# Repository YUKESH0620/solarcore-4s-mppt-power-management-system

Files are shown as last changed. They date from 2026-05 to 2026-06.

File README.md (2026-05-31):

# Solar Energy Harvesting and Battery Management Platform (STM32)  
## SolarCore-4S MPPT Power Management System

## 1. Project Banner










---

## 2. Project Overview

SolarCore-4S MPPT Power Management System is an embedded power electronics platform focused on solar energy harvesting, battery charging, battery management, and protected multi-rail power distribution. The design integrates a dedicated embedded control node based on **STM32F103C8T6**, a **BQ76920** battery management subsystem for 4S LiFePO4 supervision, and supporting power-stage/control interfaces for charge-discharge path management.

The platform architecture is modular at schematic and PCB level, enabling clear partitioning of solar input conditioning, MPPT-oriented conversion stages, battery protection, sensing, and regulated output distribution. The hardware has been developed through a professional PCB workflow in **Altium Designer**, including completed schematic capture, 4-layer layout, and Draftsman documentation generation.  

This repository documents the hardware architecture and design workflow. Hardware manufacturing and validation are pending.

---

## 3. Key Features

| Feature | Description |
|---|---|
| MPPT Energy Harvesting | Solar input processing architecture prepared for MPPT-driven energy extraction workflow |
| STM32 Control | Central embedded supervision and control using STM32F103C8T6 |
| 4S LiFePO4 Monitoring | Multi-cell battery stack monitoring architecture for 4S LiFePO4 systems |
| BQ76920 Protection | Cell monitoring and protection support through BQ76920 BMS IC |
| Charge/Discharge Control | Dedicated charge and discharge path control stages in hardware |
| Protected Outputs | Output connectors include protection-focused design intent |
| Power Distribution | Multi-rail distribution strategy for downstream loads |
| USB-C Debug Interface | USB Type-C debug/programming interface via CP2102N USB-UART bridge |
| Battery Monitoring | Voltage/current observation paths for embedded diagnostics |
| 4 Layer PCB Design | Layered signal-power-ground architecture for improved layout control |
| Draftsman Documentation | Formal assembly and fabrication-oriented documentation generated |
| Manufacturing Package Generation | Manufacturing outputs prepared (Gerber, NC drill, BOM, and related files) |

---

## 4. System Architecture

```mermaid
flowchart LR
    SI[Solar Input] --> IP[Input Protection]
    IP --> MPPT[MPPT Buck Converter]
    MPPT --> BCN[Battery Charging Node]
    BCN --> CDP[Charge/Discharge Protection]
    CDP --> BP[4S LiFePO4 Battery Pack]

    BP --> BMS[BQ76920 BMS]
    BP --> PDS[Power Distribution System]

    PDS --> R12[12V Rail]
    PDS --> R5[5V Rail]
    PDS --> R33[3.3V Rail]
    PDS --> PO[Protected Outputs]

    STM[STM32F103C8T6] <--> BMS
    STM <--> CS[Current Sensing]
    STM <--> VS[Voltage Sensing]
    STM <--> USB[USB Debug]
```

---

## 5. Hardware Architecture Overview

The hardware is partitioned into functionally distinct yet electrically integrated subsystems:

- **Solar Input Subsystem**  
  Accepts photovoltaic input and routes energy through front-end protection and conditioning stages before converter entry.

- **MPPT Subsystem**  
  Implements the hardware path required for MPPT-controlled conversion and battery charging node regulation.

- **Current Sensing Subsystem**  
  Provides analog/current feedback paths for embedded measurement and control-loop observability.

- **Voltage Sensing Subsystem**  
  Enables monitored voltage points across input, battery, and distribution nodes for supervisory logic.

- **Battery Protection Subsystem**  
  Uses BQ76920-centric monitoring/protection architecture for a 4S LiFePO4 pack context.

- **Power Switching Subsystem**  
  Controls charge/discharge path gating and operating-state transitions through dedicated switching stages.

- **Power Distribution Subsystem**  
  Distributes stored energy into required system rails and protected load outputs.

- **Output Protection Subsystem**  
  Integrates protective output routing strategy for external interfaces and load-side safety.

- **USB Debug Subsystem**  
  CP2102N-based USB-UART communication interface for firmware debug/programming workflow.

- **Embedded Controller Subsystem**  
  STM32F103C8T6 supervises sensing, BMS communication, and control sequencing at system level.

---

## 6. Complete Schematic Documentation

### Sheet 1 – System Architecture



- **What it does:** Defines top-level electrical partitioning and subsystem interconnections.  
- **How it connects:** Serves as the integration map linking energy path, control path, sensing path, and interfaces.  
- **Important components:** System-level interconnect blocks, power path references, controller interaction boundaries.  
- **Why it exists:** Establishes traceable architecture before detailed per-sheet implementation.

### Sheet 2 – STM32 Controller and Monitoring System



- **What it does:** Implements the STM32F103C8T6 control core and measurement interface endpoints.  
- **How it connects:** Interfaces with sensing networks, BMS communication paths, and debug/programming ports.  
- **Important components:** STM32F103C8T6, analog acquisition interfaces, communication lines, support passives.  
- **Why it exists:** Centralizes supervisory control and monitoring signal acquisition.

### Sheet 3 – 4S LiFePO4 Battery Management System (BMS)



- **What it does:** Defines multi-cell monitoring and battery protection topology for 4S LiFePO4.  
- **How it connects:** Ties directly to the battery stack and exchanges status/control data with the controller domain.  
- **Important components:** BQ76920 and associated sensing/protection support network.  
- **Why it exists:** Provides battery safety monitoring architecture and protected battery operation framework.

### Sheet 4 – Charge and Discharge Protection Stage



- **What it does:** Implements controlled charge/discharge path switching and protection behavior.  
- **How it connects:** Sits between charging node, battery pack, and downstream distribution interfaces.  
- **Important components:** IR2104-based drive/control elements and switching-stage support circuitry.  
- **Why it exists:** Enables controlled energy flow while enforcing protection-focused operating transitions.

### Sheet 5 – Output Connectors and Protection



- **What it does:** Defines external output connectors and protection elements for load interfacing.  
- **How it connects:** Receives power from distribution rails and routes to protected output endpoints.  
- **Important components:** Output connectors, protection devices, interface conditioning components.  
- **Why it exists:** Standardizes safe external power access points.

### Sheet 6 – Power Distribution and Voltage Rails



- **What it does:** Implements rail generation/distribution strategy for system and external loads.  
- **How it connects:** Receives upstream battery-sourced power and feeds 12V, 5V, and 3.3V domains.  
- **Important components:** LM3478-related control/distribution stage and rail routing support circuitry.  
- **Why it exists:** Provides organized multi-rail power availability across platform domains.

### Sheet 7 – USB Type-C Debug and Programming Interface



- **What it does:** Provides USB Type-C based debug/programming communication access.  
- **How it connects:** Bridges USB interface to MCU UART/debug domain through CP2102N.  
- **Important components:** CP2102N, USB Type-C connector, protection/interface passives.  
- **Why it exists:** Supports embedded development workflow and diagnostics without dedicated external adapters.

---

## 7. PCB Design Overview

The PCB is implemented as a **4-layer stackup** in Altium Designer:

| Layer | Function |
|---|---|
| Layer 1 | Top Signal |
| Layer 2 | Ground Plane |
| Layer 3 | Power Plane |
| Layer 4 | Bottom Signal |

Design strategy emphasizes:

- **Power integrity:** Controlled distribution over dedicated power plane regions and short high-current paths.  
- **Ground return paths:** Continuous ground reference on Layer 2 to reduce loop area and improve return continuity.  
- **Noise control:** Functional zoning between switching power stages, analog sensing, and controller/debug sections.  
- **Power distribution:** Structured rail routing from battery/power stages to 12V, 5V, and 3.3V destinations.  
- **Thermal considerations:** Copper utilization and via-based heat spreading around power-dense regions.  
- **Placement methodology:** Source-to-load path minimization and subsystem clustering by function.

---

## 8. PCB Layout Strategy

- **Power stage placement:** Converter and switching stages positioned to minimize high-di/dt loop lengths.  
- **Controller placement:** STM32 and monitoring circuits placed in a lower-noise control region.  
- **BMS placement:** BQ76920 and cell monitoring network grouped for short, coherent battery sense routing.  
- **USB placement:** USB Type-C and CP2102N placed for clean interface routing and practical access.  
- **Connector placement:** Power/output connectors arranged for clear current flow and service accessibility.  
- **Routing methodology:** Hierarchical routing from high-power nets first, followed by control/analog interfaces.  
- **Grounding strategy:** Ground-plane continuity maintained with deliberate partition-aware return management.  
- **Thermal vias:** Used near thermally active components to improve heat transfer into internal copper.  
- **Power planes:** Layer 3 segmented/organized to support multiple voltage domains and controlled distribution.  
- **Manufacturability considerations:** Clearances, drill constraints, and assembly access considered during layout finalization.

---

## 9. PCB Images

## PCB Top View



Top-side view showing component distribution, power-stage zoning, and control-domain placement.

## PCB Bottom View



Bottom-side view highlighting complementary routing channels, plane interactions, and connector breakout strategy.

## PCB Perspective View



Perspective rendering for holistic visualization of mechanical placement balance and subsystem segregation.

---

## 10. Draftsman Documentation

## Assembly Drawing



Documents component references, placement orientation, and assembly guidance for board population workflow.

## Layer Documentation



Provides per-layer visual references and stack representation to support fabrication and design review.

## Manufacturing Documentation



Consolidates production-facing notes, callouts, and output package references for fabrication handoff.

---

## 11. Manufacturing Outputs

| Output | Status |
|---|---|
| Gerbers | Generated |
| NC Drill Files | Generated |
| Assembly Drawings | Generated |
| Fabrication Drawings | Generated |
| BOM | Generated |
| Pick and Place Data | Generated |
| PCB PDF | Generated |
| Schematic PDF | Generated |

---

## 12. Firmware Architecture

```mermaid
flowchart TD
    A[Startup] --> B[Hardware Initialization]
    B --> C[ADC Sampling]
    C --> D[Current Measurement]
    D --> E[Voltage Measurement]
    E --> F[BMS Monitoring]
    F --> G[MPPT Control Loop]
    G --> H[Power Management]
    H --> I[Fault Detection]
    I --> J[User Feedback]
    J --> C
```

---

## 13. Firmware Workflow

- **STM32 role:** Central execution node for supervisory logic and subsystem coordination.  
- **ADC acquisition:** Periodic analog sampling for operational observability.  
- **Current sensing:** Charge/discharge path current data is acquired for control and protection context.  
- **Voltage sensing:** Battery/system voltages are monitored for state supervision.  
- **BMS communication:** Controller interfaces with BMS telemetry/protection information paths.  
- **Battery monitoring:** Multi-parameter battery condition tracking supports safe workflow decisions.  
- **Fault management:** Fault checks gate protective responses and user-visible status handling.  
- **Future MPPT implementation:** Control algorithm refinement and hardware-coupled tuning are planned after bring-up.

---

## 14. Repository Structure

```text
SolarCore-4S MPPT Power Management System/
├── Docs/
├── Hardware/
├── PCB/
├── Schematics/
├── Draftsman/
├── Firmware/
├── Manufacturing/
├── Images/
└── BOM/
```

---

## 15. Design Highlights

| Area | Implementation |
|---|---|
| Controller | STM32F103C8T6 |
| Battery Management | BQ76920 |
| Gate Drive | IR2104 |
| Power Distribution Control | LM3478 |
| USB-UART Interface | CP2102N |
| PCB Technology | 4-Layer PCB |
| Distribution Topology | Multi-rail protected power distribution |
| Debug Interface | USB Type-C debug/programming path |

---

## 16. Future Development

The following activities are planned for subsequent project phases:

- PCB manufacturing and fabrication release execution  
- Hardware assembly and staged bring-up  
- Firmware development completion and integration  
- MPPT functional validation on manufactured hardware  
- Thermal characterization under defined operating scenarios  
- Efficiency measurements across representative load/input conditions  
- System-level optimization based on bring-up and validation results

---

## 17. Project Status

- [x] System Architecture
- [x] Schematic Design
- [x] PCB Layout
- [x] Draftsman Documentation
- [x] Manufacturing Files
- [ ] PCB Fabrication
- [ ] Assembly
- [ ] Firmware Development
- [ ] Hardware Bring-Up
- [ ] Validation Testing

> Current status: Hardware design artifacts are complete; manufacturing and hardware validation are pending.

---

## 18. License

This project is licensed under the **Creative Commons Attribution-NonCommercial-NoDerivatives 4.0 International License (CC BY-NC-ND 4.0)**.

### You are permitted to:

- View and study the project
- Use the project for educational purposes
- Share links to this repository
- Reference the work with proper attribution

### You may NOT:

- Use any part of this project for commercial purposes
- Modify and redistribute the design files
- Reproduce the PCB, schematic, firmware, or documentation for commercial products
- Publish derivative works based on this project without explicit permission

All design files, schematics, PCB layouts, firmware, documentation, images, and manufacturing outputs remain the intellectual property of the author unless otherwise stated.

For licensing inquiries or commercial permissions, please contact the author.

© 2026 Yukesh S. All Rights Reserved.

---

## 19. Author

**Yukesh S**  
Embedded Systems and PCB Design Enthusiast
For project discussions, feedback, or collaboration opportunities, please open an issue in this repository.

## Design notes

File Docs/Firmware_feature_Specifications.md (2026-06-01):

# Firmware Feature Specification

## Overview

This document defines the firmware architecture, software modules, operating modes, and future capabilities of the SolarCore-4S MPPT Power Management System.

The firmware is intended to run on the STM32F103C8T6 microcontroller and provide:

- Battery monitoring
- BMS supervision
- Fault management
- User interface control
- Communication services
- Future MPPT implementation
- Expansion module support

---

# MCU Information

| Parameter | Value |
|---|---|
| MCU | STM32F103C8T6 |
| Core | ARM Cortex-M3 |
| Clock | 72 MHz |
| IDE | STM32CubeIDE |
| Language | C |
| HAL | STM32 HAL Drivers |

---

# Firmware Architecture

The firmware shall be organized into independent modules.

```text
Application Layer
│
├── System Manager
├── Battery Manager
├── MPPT Controller
├── Fault Manager
├── User Interface Manager
├── Communication Manager
├── Output Manager
└── Data Logger
│
Hardware Abstraction Layer
│
STM32 Peripherals
```

---

# System Manager

## Purpose

Central firmware coordinator.

### Responsibilities

- System initialization
- State management
- Scheduler execution
- Module coordination
- Startup sequence
- Shutdown sequence

### Startup Tasks

1. Configure clocks
2. Initialize GPIO
3. Initialize ADC
4. Initialize UART
5. Initialize I²C
6. Initialize timers
7. Initialize indicators
8. Verify BMS communication
9. Enter operational state

---

# Battery Manager

## Purpose

Monitor battery condition.

### Inputs

| Signal | STM32 Pin |
|---|---|
| BMS_ALERT | PA0 |
| FB_NODE | PA4 |
| CURRENT_SENSE | PA5 |

### Responsibilities

- Battery voltage estimation
- State of charge estimation
- Charge state determination
- Discharge monitoring
- Protection coordination

### Future Features

- Coulomb counting
- Battery health estimation
- Cycle counting
- Runtime prediction

---

# MPPT Controller

## Status

Planned

---

## Purpose

Maximize solar energy extraction.

### PWM Output

| Signal | STM32 Pin |
|---|---|
| PWM_OUT | PA8 |

### Future Inputs

| Signal | STM32 Pin |
|---|---|
| PV Voltage Sense | PA3 |
| Current Sense | PA5 |

### Planned Algorithm

Perturb and Observe (P&O)

---

## Workflow

```text
Measure Voltage
Measure Current
Calculate Power
Adjust Duty Cycle
Measure Again
Repeat
```

---

## Future Enhancements

- Incremental Conductance
- Adaptive Step Size
- Temperature Compensation
- Hybrid MPPT Algorithms

---

# Fault Manager

## Purpose

Detect and respond to abnormal conditions.

### Monitored Sources

- BQ76920
- Current Sensor
- Voltage Measurements
- Communication Interfaces
- Watchdog

### Fault Categories

| Category | Description |
|---|---|
| Battery | Cell faults |
| Current | Overcurrent |
| Voltage | Overvoltage |
| Communication | Interface faults |
| Firmware | Internal faults |

---

## Fault Responses

| Severity | Action |
|---|---|
| INFO | Log Event |
| WARNING | User Notification |
| MAJOR | Disable Function |
| CRITICAL | Emergency Shutdown |

---

# User Interface Manager

## Purpose

Manage LEDs and buzzer.

---

## Battery LEDs

| Pin | Function |
|---|---|
| PB0 | BAT_LEVEL1 |
| PB1 | BAT_LEVEL2 |
| PB2 | BAT_LEVEL3 |
| PB3 | BAT_LEVEL4 |
| PB4 | BAT_LEVEL5 |

Functions:

- Battery level display
- Charging animation
- Fault indication
- Startup diagnostics

---

## Buzzer

| Pin | Function |
|---|---|
| PB7 | BUZ_CTRL |

Functions:

- Startup beep
- Fault alerts
- Low battery warnings
- Charge completion indication

---

## User Button

| Pin | Function |
|---|---|
| PA1 | USER_BUTTON |

Potential Actions:

- Wake system
- Show battery level
- Toggle display pages
- Enter diagnostics mode

---

# OLED Display Manager

## Status

Future Expansion

### Interface

| Signal | STM32 Pin |
|---|---|
| SDA | PB6 |
| SCL | PB5 |

---

## Planned Display Pages

### Page 1

Battery Information

```text
Voltage
Percentage
Status
```

### Page 2

Solar Information

```text
PV Voltage
PV Current
PV Power
```

### Page 3

System Status

```text
Faults
Outputs
Communication
```

---

# Communication Manager

## UART1

### Purpose

Debug Interface

| Signal | Pin |
|---|---|
| TX | PA9 |
| RX | PA10 |

Applications:

- Debug logging
- Diagnostics
- Firmware development

---

## UART3

### Purpose

Expansion Interface

| Signal | Pin |
|---|---|
| TX | PB10 |
| RX | PB11 |

Applications:

- ESP32
- Bluetooth
- LoRa
- GSM
- Telemetry

---

# ESP32 Telemetry Manager

## Status

Future Expansion

Potential Features:

- Web Dashboard
- MQTT
- WiFi Monitoring
- OTA Updates
- Mobile App Support
- Cloud Integration

---

# CAN Communication

## Status

Reserved

| Signal | Pin |
|---|---|
| CAN_TX | PA11 |
| CAN_RX | PA12 |

Potential Applications:

- Industrial Systems
- Vehicle Networks
- Distributed Power Systems

---

# Output Manager

## Purpose

Manage system outputs.

Responsibilities:

- Output enable
- Output disable
- Load monitoring
- Protection coordination

Future Features:

- Smart load control
- Priority load management
- Emergency shutdown

---

# Data Logger

## Status

Future Expansion

Potential Logged Parameters:

- Battery voltage
- Current measurements
- Fault events
- Charge cycles
- Runtime statistics

Storage Options:

- Internal Flash
- External EEPROM
- SD Card

---

# Watchdog Manager

## Purpose

Recover from firmware failures.

Functions:

- Detect lockups
- Force restart
- Maintain system reliability

---

# Operating States

## Startup

```text
Power Applied
Initialize Hardware
Run Diagnostics
Enter Ready State
```

---

## Idle

```text
Monitoring Active
Charging Disabled
```

---

## Charging

```text
Battery Charging Active
Monitoring Active
```

---

## Fault

```text
Protection Triggered
User Alerted
Recovery Required
```

---

## Shutdown

```text
Outputs Disabled
Low Power State
```

---

# Future Firmware Roadmap

## Revision B

- PV Voltage Measurement
- Basic MPPT

## Revision C

- OLED Dashboard
- ESP32 Telemetry

## Revision D

- Data Logging
- CAN Support

## Revision E

- Advanced MPPT
- Cloud Monitoring

---

# Firmware Development Priority

| Priority | Feature |
|---|---|
| 1 | Hardware Bring-Up |
| 2 | ADC Acquisition |
| 3 | BMS Monitoring |
| 4 | LED Indicators |
| 5 | Buzzer Control |
| 6 | Fault Handling |
| 7 | UART Debug |
| 8 | MPPT Implementation |
| 9 | OLED Support |
| 10 | ESP32 Telemetry |

---

# Revision Information

Document Version: 1.0

Applicable Hardware Revision: Rev A

Board:

SolarCore-4S MPPT Power Management System

Author:

Yukesh S

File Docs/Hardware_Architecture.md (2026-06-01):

# Hardware Architecture

## Overview

The SolarCore-4S MPPT Power Management System is a modular embedded energy harvesting and battery management platform designed around an STM32F103C8T6 microcontroller and a BQ76920 battery monitoring system.

The architecture combines:

- Solar Energy Harvesting
- Battery Charging
- Battery Protection
- Embedded Monitoring
- Power Distribution
- Expansion Interfaces
- Future MPPT Capability

The platform is organized into multiple independent hardware subsystems to improve maintainability, scalability, and future development.

---

# System Block Diagram

```text
                    ┌─────────────────┐
                    │   Solar Input   │
                    └────────┬────────┘
                             │
                             ▼
                  ┌────────────────────┐
                  │ Input Protection   │
                  └────────┬───────────┘
                           │
                           ▼
               ┌─────────────────────────┐
               │ Charging Power Stage    │
               └──────────┬──────────────┘
                          │
                          ▼
               ┌─────────────────────────┐
               │ 4S LiFePO4 Battery Pack │
               └──────────┬──────────────┘
                          │
          ┌───────────────┼───────────────┐
          │                               │
          ▼                               ▼
 ┌─────────────────┐          ┌─────────────────┐
 │ BQ76920 BMS     │          │ Protection Stage│
 └────────┬────────┘          └────────┬────────┘
          │                             │
          ▼                             ▼
 ┌────────────────────────────────────────────┐
 │ Power Distribution and Output Management   │
 └───────────────────┬────────────────────────┘
                     │
                     ▼
         ┌──────────────────────────┐
         │ Regulated Power Outputs  │
         └──────────────────────────┘

                     ▲
                     │
          ┌──────────┴──────────┐
          │ STM32F103C8T6 MCU   │
          └─────────────────────┘
```

---

# Hardware Subsystems

The design is divided into seven major hardware subsystems.

| Sheet | Subsystem |
|---|---|
| Sheet 1 | System Architecture |
| Sheet 2 | STM32 Controller and Monitoring |
| Sheet 3 | Battery Management System |
| Sheet 4 | Charge and Discharge Protection |
| Sheet 5 | Output Connectors and Protection |
| Sheet 6 | Power Distribution |
| Sheet 7 | USB-C Debug Interface |

---

# 1. System Architecture

## Purpose

Acts as the top-level integration sheet and defines how all hardware blocks interact.

### Responsibilities

- System connectivity
- Power flow definition
- Signal flow organization
- Hierarchical schematic management

### Major Interfaces

- Solar Input
- Battery Pack
- BMS
- STM32 Controller
- Power Distribution
- Debug Interface

### Design Objective

Provide a clean separation between:

- Power Electronics
- Battery Management
- Embedded Control
- User Interfaces

---

# 2. STM32 Controller and Monitoring System

## Purpose

The STM32F103C8T6 serves as the central controller for the entire platform.

### Responsibilities

- Battery monitoring
- Fault management
- ADC acquisition
- User interface control
- Communication handling
- Future MPPT control

---

## Analog Monitoring

### Battery Voltage

Pin:

```text
PA4
```

Signal:

```text
FB_NODE
```

Purpose:

- Battery voltage measurement
- Charge monitoring
- System diagnostics

---

### Current Measurement

Pin:

```text
PA5
```

Signal:

```text
CURRENT_SENSE_OUT
```

Purpose:

- Charge current monitoring
- Future MPPT calculations
- Power estimation

---

## BMS Alert Monitoring

Pin:

```text
PA0
```

Signal:

```text
BMS_ALERT
```

Purpose:

Immediate notification of battery protection events.

---

## User Interface

Connected Devices:

- Battery LEDs
- Status LEDs
- Buzzer
- User Button

---

## Communication Interfaces

### UART1

Connected to:

```text
CP2102N
```

Purpose:

- Debugging
- Firmware upload
- Serial diagnostics

---

### UART3

Reserved for:

- ESP32
- Telemetry
- Future wireless communication

---

### I²C

Reserved for:

- OLED display
- External sensors
- Expansion peripherals

---

# 3. Battery Management System

## Purpose

Provide hardware-level battery monitoring and protection.

---

## Main Component

```text
BQ76920
```

---

## Functions

- Cell monitoring
- Overvoltage protection
- Undervoltage protection
- Charge overcurrent protection
- Discharge overcurrent protection

---

## Battery Configuration

| Parameter | Value |
|---|---|
| Chemistry | LiFePO4 |
| Configuration | 4S |
| Nominal Voltage | 12.8V |
| Maximum Voltage | 14.6V |

---

## BMS Communication

The BQ76920 reports fault conditions through:

```text
BMS_ALERT
```

connected to:

```text
PA0
```

---

# 4. Charge and Discharge Protection Stage

## Purpose

Provide safe control of battery charging and battery discharge.

---

## Main Components

```text
AO4407A MOSFETs
```

---

## Functions

- Charge path control
- Discharge path control
- Reverse current protection
- Battery isolation

---

## Protection Events

The subsystem responds to:

- Overvoltage
- Undervoltage
- Overcurrent
- Short circuit conditions

---

# 5. Output Connectors and Protection

## Purpose

Provide protected access to system power rails.

---

## Features

- Output connectors
- Reverse protection
- Load connection interface
- Expansion support

---

## Design Goals

- Safe load connection
- Simplified external integration
- Future expansion capability

---

# 6. Power Distribution System

## Purpose

Generate and distribute power throughout the platform.

---

## Available Rails

| Rail | Purpose |
|---|---|
| SYS_VBAT | Battery Rail |
| V12_SYS | System Power |
| V5_SYS | Logic and Expansion |
| 3V3_SYS | MCU Supply |
| VBOOST_OUT | Boost Output |

---

## Design Objectives

- Stable voltage distribution
- Low impedance power delivery
- Future peripheral support

---

## Power Consumers

- STM32
- BQ76920
- CP2102N
- Expansion Interfaces
- External Peripherals

---

# 7. USB-C Debug and Programming Interface

## Purpose

Provide firmware development and debugging access.

---

## Main Components

```text
USB Type-C Connector
CP2102N
```

---

## Features

- Serial communication
- Firmware development
- Debug logging
- Programming support

---

## MCU Connection

| Signal | STM32 Pin |
|---|---|
| UART_TX | PA9 |
| UART_RX | PA10 |

---

# User Interface Architecture

## Battery LEDs

| Pin | Function |
|---|---|
| PB0 | BAT_LEVEL1 |
| PB1 | BAT_LEVEL2 |
| PB2 | BAT_LEVEL3 |
| PB3 | BAT_LEVEL4 |
| PB4 | BAT_LEVEL5 |

Purpose:

Battery capacity indication.

---

## Buzzer

Pin:

```text
PB7
```

Purpose:

Audible user notifications.

---

## User Button

Pin:

```text
PA1
```

Purpose:

Future user interaction.

---

# Expansion Architecture

The design intentionally reserves resources for future functionality.

---

## OLED Interface

| Signal | STM32 Pin |
|---|---|
| SDA | PB6 |
| SCL | PB5 |

Potential Features:

- Battery Dashboard
- Charging Status
- Fault Information

---

## ESP32 Interface

| Signal | STM32 Pin |
|---|---|
| TX | PB10 |
| RX | PB11 |

Potential Features:

- WiFi
- MQTT
- Remote Monitoring

---

## CAN Interface

Reserved Pins:

| Signal | STM32 Pin |
|---|---|
| CAN_TX | PA11 |
| CAN_RX | PA12 |

Future Applications:

- Industrial Networks
- Distributed Power Systems
- Vehicle Integration

---

# Future MPPT Architecture

## Reserved Resource

Pin:

```text
PA3
```

Purpose:

Future photovoltaic voltage sensing.

---

## Planned Measurements

- PV Voltage
- PV Current
- PV Power

---

## Planned Algorithms

- Perturb and Observe
- Incremental Conductance

---

# Design Philosophy

The SolarCore-4S MPPT Power Management System was designed as a modular embedded energy platform rather than a single-purpose charger.

The architecture prioritizes:

- Safety
- Expandability
- Maintainability
- Firmware Flexibility
- Professional PCB Design Practices

The hardware foundation supports future development in:

- MPPT Control
- Wireless Monitoring
- Data Logging
- Industrial Communication
- Advanced Battery Analytics

---

## Revision Information

Document Version: 1.0

Board Revision: Rev A

Project:

SolarCore-4S MPPT Power Management System

Author:

Yukesh S

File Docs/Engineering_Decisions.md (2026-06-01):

# Engineering Decisions

## Overview

This document explains the major engineering decisions made during the design of the SolarCore-4S MPPT Power Management System.

The objective was not simply to build a battery charger, but to develop a modular embedded power management platform capable of supporting future expansion, firmware development, and advanced energy harvesting algorithms.

The design philosophy focused on:

- Modularity
- Scalability
- Maintainability
- Firmware Flexibility
- Professional PCB Design Practices
- Future Expandability

---

# Why STM32F103C8T6?

## Decision

STM32F103C8T6 was selected as the primary system controller.

---

## Requirements

The controller needed to provide:

- Multiple ADC channels
- PWM generation
- UART communication
- I²C communication
- Sufficient GPIO resources
- Development tool support
- Low cost
- Strong ecosystem

---

## Advantages

### ADC Resources

The design requires monitoring:

- Battery voltage
- Current sensor output
- Future PV voltage sensing

STM32 provides sufficient ADC resources for current and future requirements.

---

### Timer Resources

The MPPT architecture requires PWM generation.

STM32 timers support:

- High-resolution PWM
- Future complementary outputs
- Duty cycle control
- Frequency control

---

### Development Ecosystem

STM32 offers:

- STM32CubeIDE
- STM32 HAL
- Extensive documentation
- Community support
- Professional industry adoption

---

### Expansion Capability

Unused GPIO resources remain available for:

- CAN
- OLED
- Wireless modules
- Temperature monitoring
- Future peripherals

---

## Conclusion

STM32F103C8T6 provides an excellent balance between cost, capability, ecosystem support, and future scalability.

---

# Why BQ76920?

## Decision

The BQ76920 was selected as the battery monitoring and protection IC.

---

## Requirements

The system required:

- Cell monitoring
- Overvoltage protection
- Undervoltage protection
- Charge overcurrent protection
- Discharge overcurrent protection
- Hardware-level safety

---

## Advantages

### Dedicated Battery Protection

Battery safety should not depend solely on firmware.

The BQ76920 provides independent hardware protection.

---

### Individual Cell Monitoring

The IC enables:

- Cell voltage monitoring
- Cell imbalance detection
- Future balancing strategies

---

### Alert Interface

The BMS_ALERT signal allows the STM32 to react quickly to battery events.

---

## Conclusion

The BQ76920 provides a reliable and industry-proven battery management solution for multi-cell lithium battery systems.

---

# Why IR2104?

## Decision

The IR2104 was selected as the gate driver for the future MPPT power stage.

---

## Requirements

The MPPT architecture requires:

- High-side MOSFET control
- Low-side MOSFET control
- Bootstrap operation
- Fast switching capability

---

## Advantages

### High-Side Drive Capability

The IR2104 simplifies high-side N-channel MOSFET control.

---

### Industry Adoption

The device is widely used in:

- Buck converters
- Motor drives
- Power supplies
- Power electronics development

---

### Simplicity

The device provides a straightforward implementation path for future MPPT firmware development.

---

## Conclusion

The IR2104 offers a practical and proven solution for driving the MPPT switching stage.

---

# Why LM3478?

## Decision

The LM3478 was selected for the power conversion and distribution subsystem.

---

## Requirements

The design required:

- Flexible power conversion
- Expansion capability
- Efficient power distribution

---

## Advantages

### Wide Application Range

The LM3478 supports:

- Boost converters
- SEPIC converters
- Flyback converters

---

### Design Flexibility

The controller enables future power architecture experimentation and optimization.

---

## Conclusion

The LM3478 provides flexibility and supports future design evolution.

---

# Why a 4-Layer PCB?

## Decision

A 4-layer PCB stackup was selected.

---

## Requirements

The project combines:

- Power electronics
- Battery management
- Embedded control
- Communication interfaces

These functions benefit significantly from a dedicated plane structure.

---

## Selected Stackup

### Layer 1

Top Signal

### Layer 2

Ground Plane

### Layer 3

Power Plane

### Layer 4

Bottom Signal

---

## Advantages

### Improved Ground Integrity

A continuous ground plane reduces:

- Noise
- Ground bounce
- Return path impedance

---

### Improved Power Distribution

Dedicated power routing improves:

- Voltage stability
- Current handling
- Routing simplicity

---

### Better EMI Performance

The stackup helps control:

- Switching noise
- Signal integrity
- Radiated emissions

---

### Easier Routing

The architecture contains:

- Battery management circuitry
- Multiple interfaces
- Power conversion stages

A 4-layer board significantly simplifies routing.

---

## Conclusion

The 4-layer architecture improves electrical performance and reflects professional PCB design practice.

---

# Why USB Type-C?

## Decision

USB Type-C was selected for the programming and debug interface.

---

## Requirements

The board required:

- Firmware upload capability
- Serial debugging
- Reliable connectivity

---

## Advantages

### Modern Interface

USB Type-C is widely available and eliminates cable orientation concerns.

---

### Development Convenience

Developers can:

- Program firmware
- Monitor debug messages
- Access diagnostics

using a single connection.

---

## Conclusion

USB Type-C improves usability and provides a modern development experience.

---

# Why UART3 Expansion?

## Decision

UART3 was reserved for future expansion.

---

## Requirements

Future communication capabilities were considered during the initial design phase.

---

## Potential Applications

### ESP32 Integration

Possible features:

- WiFi
- MQTT
- OTA updates
- Remote monitoring

---

### Wireless Modules

Possible integrations:

- Bluetooth
- LoRa
- GSM

---

## Conclusion

Reserving UART3 enables future communication upgrades without hardware redesign.

---

# Why OLED Support?

## Decision

An I²C expansion header was included.

---

## Motivation

Providing user feedback directly on the board improves usability.

---

## Possible Future Features

- Battery percentage
- Cell voltages
- Charging status
- Fault messages
- Solar statistics
- System diagnostics

---

## Conclusion

The I²C interface enables future user-interface enhancements with minimal hardware changes.

---

# Why Reserve CAN Resources?

## Decision

CAN resources were reserved on PA11 and PA12.

---

## Motivation

Industrial and automotive systems frequently use CAN communication.

Providing future support increases platform flexibility.

---

## Potential Applications

- Industrial battery systems
- Distributed power systems
- Energy management networks
- Vehicle integration

---

## Conclusion

Although unused in Revision A, CAN support was considered during architecture planning.

---

# Why Reserve PA3 for PV Voltage Measurement?

## Decision

PA3 was intentionally reserved for future photovoltaic voltage sensing.

---

## Design Observation

During development, battery monitoring and system architecture were prioritized.

A direct PV voltage measurement path was not implemented in Revision A.

---

## Future Improvement

An external voltage sensing circuit can be connected to the reserved interface.

This enables:

- PV voltage monitoring
- True MPPT implementation
- Power calculations
- Solar operating point tracking

---

## Engineering Benefit

Reserving the resource prevents future firmware limitations and allows the platform to evolve without major MCU changes.

---

# Why Multiple Reserved GPIOs?

## Decision

Several GPIOs were intentionally left unused.

---

## Motivation

Future requirements are difficult to predict during early hardware development.

Reserved resources allow:

- Additional sensors
- Relays
- Fan control
- Communication interfaces
- Data logging
- User interface improvements

---

## Conclusion

Strategic GPIO reservation improves long-term maintainability and scalability.

---

# Design Philosophy

The SolarCore-4S MPPT Power Management System was designed as a learning platform, development platform, and future expansion platform.

The design prioritizes:

- Safe battery operation
- Modular architecture
- Embedded system development
- Professional PCB design
- Expandability
- Maintainability

Rather than optimizing for a single application, the platform was intentionally designed to support future experimentation, firmware development, and advanced power management features.

---

## Revision Information

Document Version: 1.0

Board Revision: Rev A

Project:

SolarCore-4S MPPT Power Management System

Author:

Yukesh S

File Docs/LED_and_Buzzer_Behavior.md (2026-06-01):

# LED and Buzzer Behavior Specification

## Overview

The SolarCore-4S MPPT Power Management System includes a visual and audible notification subsystem implemented using:

- 5 Battery Level LEDs
- 1 BMS Fault LED
- 1 Charging Status LED
- 1 Discharging Status LED
- 1 Power Status LED
- 1 Firmware-Controlled Buzzer

The behavior described in this document represents the recommended firmware implementation for Hardware Revision A.

---

# Indicator Summary

| Indicator | Purpose |
|---|---|
| BAT_LEVEL1 | Battery Capacity Display |
| BAT_LEVEL2 | Battery Capacity Display |
| BAT_LEVEL3 | Battery Capacity Display |
| BAT_LEVEL4 | Battery Capacity Display |
| BAT_LEVEL5 | Battery Capacity Display |
| BMS Fault LED | BMS Alert Indication |
| Charging LED | Charging Activity |
| Discharging LED | Load Activity |
| Power LED | System Power Presence |
| Buzzer | Audible Notifications |

---

# STM32 Pin Assignment

## Battery Indicators

| LED | STM32 Pin |
|---|---|
| BAT_LEVEL1 | PB0 |
| BAT_LEVEL2 | PB1 |
| BAT_LEVEL3 | PB2 |
| BAT_LEVEL4 | PB3 |
| BAT_LEVEL5 | PB4 |

---

## Buzzer

| Signal | STM32 Pin |
|---|---|
| BUZ_CTRL | PB7 |

---

# Battery Capacity Display

## Normal Operating Mode

The battery level LEDs indicate the estimated state of charge (SOC) of the connected 4S LiFePO4 battery pack.

### Recommended Mapping

| Battery Percentage | LED Status |
|---|---|
| 0% – 20% | LED1 ON |
| 20% – 40% | LED1 + LED2 ON |
| 40% – 60% | LED1 + LED2 + LED3 ON |
| 60% – 80% | LED1 + LED2 + LED3 + LED4 ON |
| 80% – 100% | All LEDs ON |

---

# Startup Sequence

When the system powers up:

### Recommended Animation

Step 1

```text
LED1
```

Step 2

```text
LED1 LED2
```

Step 3

```text
LED1 LED2 LED3
```

Step 4

```text
LED1 LED2 LED3 LED4
```

Step 5

```text
LED1 LED2 LED3 LED4 LED5
```

Then return to normal battery display mode.

Purpose:

- Verify LEDs are functional
- Provide visual startup confirmation
- Improve user experience

---

# Charging Indication

## Charging Active

Recommended Pattern:

```text
Running LED Animation
```

Example:

```text
LED1
LED2
LED3
LED4
LED5
Repeat
```

Purpose:

Clearly indicate charging activity.

---

## Charging Complete

Recommended Pattern:

```text
All LEDs ON
```

for

```text
3 seconds
```

followed by normal display mode.

---

## Trickle / Float State

Recommended Pattern:

```text
All LEDs Slow Blink
```

Period:

```text
1 second ON
1 second OFF
```

---

# Low Battery Warning

## Warning Level

Battery below:

```text
20%
```

Recommended Pattern:

```text
LED1 Slow Blink
```

Purpose:

Warn user before critical discharge.

---

# Critical Battery State

## Critical Threshold

Battery below:

```text
10%
```

Recommended Pattern:

```text
LED1 Fast Blink
```

Purpose:

Immediate recharge required.

---

# Fault Display Modes

## BMS Alert

Condition:

```text
BMS_ALERT asserted
```

Possible Causes:

- Cell Overvoltage
- Cell Undervoltage
- Overcurrent
- Short Circuit

Recommended Display:

```text
All Battery LEDs Blink Simultaneously
```

Rate:

```text
4 Hz
```

---

## Communication Fault

Condition:

Loss of communication with BQ76920.

Recommended Display:

```text
LED1 + LED3 + LED5 Blink
```

Pattern:

```text
Alternating Pattern
```

Purpose:

Differentiate from battery faults.

---

## Sensor Fault

Condition:

ADC readings invalid.

Recommended Display:

```text
LED2 + LED4 Blink
```

Purpose:

Indicate measurement subsystem issue.

---

# Power LED Behavior

## System Active

Power LED:

```text
Solid ON
```

Meaning:

System operational.

---

## System Shutdown

Power LED:

```text
OFF
```

Meaning:

No system power.

---

# Charging LED Behavior

## Charging Enabled

Charging LED:

```text
Solid ON
```

Meaning:

Battery charging path active.

---

## Charging Disabled

Charging LED:

```text
OFF
```

Meaning:

Charge path disabled.

---

## Charging Fault

Charging LED:

```text
Fast Blink
```

Meaning:

Charging inhibited due to protection event.

---

# Discharging LED Behavior

## Load Active

Discharging LED:

```text
Solid ON
```

Meaning:

Battery supplying load current.

---

## Load Disabled

Discharging LED:

```text
OFF
```

Meaning:

Discharge path disabled.

---

# Audible Notification System

## Startup

Pattern:

```text
Single Short Beep
```

Duration:

```text
100 ms
```

Meaning:

System boot successful.

---

## Charging Started

Pattern:

```text
Double Beep
```

Meaning:

Charging operation detected.

---

## Charging Complete

Pattern:

```text
Triple Beep
```

Meaning:

Battery fully charged.

---

## Low Battery

Pattern:

```text
Short Beep Every 10 Seconds
```

Meaning:

Battery nearing depletion.

---

## Critical Battery

Pattern:

```text
Short Beep Every 2 Seconds
```

Meaning:

Recharge immediately.

---

## BMS Fault

Pattern:

```text
Long Continuous Tone
```

Duration:
```text
2 Seconds
```

Meaning:

Battery protection event.

---

## Communication Fault

Pattern:

```text
Three Short Pulses
```

Meaning:

BMS communication lost.

---

## Sensor Fault

Pattern:

```text
Two Long Pulses
```

Meaning:

Measurement subsystem error.

---

# Future OLED Integration

When an OLED display is connected to the I²C header, the LED indications may be supplemented with textual status information.

Possible OLED Messages:

```text
Charging
Charge Complete
Battery Low
Battery Critical
BMS Fault
Sensor Fault
System Ready
Output Enabled
```

---

# Future Firmware Expansion

Because all indicators are GPIO controlled through the STM32F103C8T6, future firmware revisions may implement:
- User-selectable alert profiles
- Silent mode
- Diagnostic mode
- Morse-code fault indications
- Configurable buzzer frequencies
- OLED-assisted status display
- Mobile app notifications through ESP32

---

# Revision Information

Document Version: 1.0
Applicable Hardware Revision: Rev A

Board:
SolarCore-4S MPPT Power Management System

Author:
Yukesh S

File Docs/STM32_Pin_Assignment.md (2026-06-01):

# STM32F103C8T6 Pin Assignment

## Overview

The SolarCore-4S MPPT Power Management System uses an STM32F103C8T6 microcontroller as the central system controller. The MCU is responsible for battery monitoring, fault handling, future MPPT control implementation, user interface management, communication interfaces, and system supervision.

This document defines the official pin assignment for Hardware Revision A.

---

# MCU Information

| Parameter | Value |
|---|---|
| MCU | STM32F103C8T6 |
| Architecture | ARM Cortex-M3 |
| Flash Memory | 64 KB |
| SRAM | 20 KB |
| Operating Voltage | 3.3V |
| Debug Interface | SWD |
| Firmware Toolchain | STM32CubeIDE |

---

# Pin Assignment Table

| Pin | Function | Module |
|---|---|---|
| PA0 | BMS_ALERT | BQ76920 |
| PA1 | USER_BUTTON | User Input |
| PA2 | Reserved | Future Expansion |
| PA3 | Reserved (Future PV Voltage Sense) | MPPT Rev-B |
| PA4 | FB_NODE Voltage Sense | ADC1_IN4 |
| PA5 | Current Sense (INA180 Output) | ADC1_IN5 |
| PA6 | Reserved | Future Expansion |
| PA7 | Reserved | Future Expansion |
| PA8 | PWM_OUT | TIM1_CH1 → IR2104 |
| PA9 | UART1_TX | CP2102N |
| PA10 | UART1_RX | CP2102N |
| PA11 | CAN_TX (Unused) | Future |
| PA12 | CAN_RX (Unused) | Future |
| PA13 | SWDIO | Programming |
| PA14 | SWCLK | Programming |
| PA15 | Unused | Reserved |
| PB0 | BAT_LEVEL1 | Battery LED 1 |
| PB1 | BAT_LEVEL2 | Battery LED 2 |
| PB2 | BAT_LEVEL3 | Battery LED 3 |
| PB3 | BAT_LEVEL4 | Battery LED 4 |
| PB4 | BAT_LEVEL5 | Battery LED 5 |
| PB5 | I2C_SCL | OLED / Expansion |
| PB6 | I2C_SDA | OLED / Expansion |
| PB7 | BUZ_CTRL | Buzzer Output |
| PB8 | Reserved | Future Expansion |
| PB9 | Reserved | Future Expansion |
| PB10 | UART3_TX | ESP32 Expansion |
| PB11 | UART3_RX | ESP32 Expansion |
| PB12 | Reserved | Future Expansion |
| PB13 | Reserved | Future Expansion |
| PB14 | Reserved | Future Expansion |
| PB15 | Reserved | Future Expansion |

---

# Functional Grouping

## Analog Inputs

### PA4 — FB_NODE Voltage Sense

Purpose:

- Battery charge node monitoring
- Voltage feedback acquisition
- MPPT feedback path
- ADC measurements

Peripheral:

ADC1_IN4

---

### PA5 — Current Sense Input

Purpose:

- INA180 current monitor output
- Charging current measurement
- Power estimation
- Future MPPT calculations

Peripheral:

ADC1_IN5

---

### PA3 — Reserved PV Voltage Input

Purpose:

Future photovoltaic voltage sensing.

Revision A PCB does not directly monitor PV panel voltage.

A dedicated external sensing interface is planned for future hardware revisions.

Planned Applications:

- True MPPT implementation
- Solar panel power calculation
- Panel operating point tracking
- Advanced energy harvesting algorithms

Peripheral:

ADC1_IN3

Status:

Reserved

---

# PWM Outputs

## PA8 — MPPT PWM Control

Signal:

PWM_OUT

Peripheral:

TIM1_CH1

Connected Device:

IR2104 Gate Driver

Purpose:

- Buck converter control
- MPPT duty cycle control
- Power regulation
- Future closed-loop energy harvesting

Status:

Reserved for future firmware implementation.

---

# Communication Interfaces

## UART1

Used for debugging and firmware development.

| Pin | Function |
|---|---|
| PA9 | UART1_TX |
| PA10 | UART1_RX |

Connected Device:

CP2102N USB-UART Bridge

Applications:

- Serial terminal
- Debug messages
- Firmware diagnostics
- Development support

---

## UART3

Reserved for future wireless and communication expansion.

| Pin | Function |
|---|---|
| PB10 | UART3_TX |
| PB11 | UART3_RX |

Applications:

- ESP32 Integration
- ESP32-S3 Integration
- Bluetooth Modules
- LoRa Communication
- GSM Modems
- Telemetry Systems
- IoT Gateways

---

## I²C Interface

Dedicated expansion bus.

| Pin | Function |
|---|---|
| PB5 | I2C_SCL |
| PB6 | I2C_SDA |

Applications:

- OLED Displays
- Environmental Sensors
- RTC Modules
- External EEPROM
- ADC Expansion
- Digital Sensors

---

# User Interface Resources

## Battery Level Indicators

Five independent battery level LEDs are provided.

| Pin | LED |
|---|---|
| PB0 | BAT_LEVEL1 |
| PB1 | BAT_LEVEL2 |
| PB2 | BAT_LEVEL3 |
| PB3 | BAT_LEVEL4 |
| PB4 | BAT_LEVEL5 |

Potential Functions:

- Battery percentage display
- Charging animation
- Diagnostic display
- Fault indication
- Startup sequence

---

## User Button

Pin:

PA1

Purpose:

General-purpose user interaction.

Possible Functions:

- Wake-up
- Status display request
- Mode selection
- Factory reset
- Firmware menu navigation

---

## Buzzer

Pin:

PB7

Signal:

BUZ_CTRL

Purpose:

Audible user feedback.

Possible Firmware Functions:

- Startup notification
- Low battery warning
- Charging complete indication
- Fault alerts
- Diagnostic feedback

Since the buzzer is GPIO-controlled, firmware can generate custom frequencies and notification patterns.

---

# Debug Interface

## SWD Programming

| Pin | Function |
|---|---|
| PA13 | SWDIO |
| PA14 | SWCLK |

Applications:

- Firmware upload
- Breakpoint debugging
- Flash programming
- System diagnostics

Supported Tools:

- ST-Link V2
- ST-Link V3
- STM32CubeIDE

---

# Future Expansion Resources

The following pins are intentionally reserved for future platform growth:

| Pin |
|------|
| PA2 |
| PA6 |
| PA7 |
| PA11 |
| PA12 |
| PA15 |
| PB8 |
| PB9 |
| PB12 |
| PB13 |
| PB14 |
| PB15 |

Potential Future Features:

- CAN Bus
- RS485
- Fan Control
- Temperature Sensors
- Relay Outputs
- Data Logging
- Smart Load Control
- Industrial Communication
- Wireless Connectivity

---

# GPIO Resource Summary

| Category | Count |
|---|---|
| Analog Inputs | 3 |
| PWM Outputs | 1 |
| UART Interfaces | 2 |
| I²C Interfaces | 1 |
| User Buttons | 1 |
| LED Outputs | 5 |
| Buzzer Outputs | 1 |
| SWD Debug Interface | 1 |
| Reserved Expansion Pins | 12 |

---

# Revision Information

Document Version: 1.0

Applicable Hardware Revision: Rev A

Board:

SolarCore-4S MPPT Power Management System

Author:

Yukesh S

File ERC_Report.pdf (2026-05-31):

### Electrical Rules Check Report

Class | Document | Message
Warning | MCU_Control.SchDoc | 3V3_SYS contains IO Pin and Power Pin objects (Pin U3-1, Pin IC1-6, Pin U3-9, Pin
| | U3-24, Pin U3-36, Pin U3-48).
Warning | MCU_Control.SchDoc | 3V3_SYS contains IO Pin and Unspecified Port objects (Pin U3-1, Port 3V3_SYS).
Warning | BMS_CORE.SchDoc | BAT_N_F contains Input Pin and Unspecified Port objects (Pin U4-17, Port BAT_N).
Warning | BMS_CORE.SchDoc | BAT_N_F contains Unspecified Port and Bidirectional Sheet Entry objects (Port BAT_N,
| | Sheet Entry U_BMS_CORE-BAT_N(I/O)).
Warning | POWER_SWITCH.SchDoc | BAT_N_F contains Unspecified Port and Bidirectional Sheet Entry objects (Port BAT_N,
| | Sheet Entry U_POWER_SWITCH-BAT_N(I/O)).
Warning | BMS_CORE.SchDoc | BMS_ALERT contains IO Pin and Output Port objects (Pin U4-20, Port BMS_ALERT).
Warning | POWER_DISTRIBUTION.SchDoc COMMON_NODE contains IO Pin and Power Pin objects (Pin U7-7, Pin U1-1).
Warning | POWER_DISTRIBUTION.SchDoc Component D7 BZX84C47LT1G has unused sub-part(s) (2).
Warning | Main_MPPT.SchDoc | Component L1 WE-PD_1260 at 205.06mm,184.48mm: Component revision is Out of
| | Date.
Warning | MCU_Control.SchDoc | Component SW1 4-1437565-9 at 119.63mm,68.58mm: Component revision is Out of
| | Date.
Warning | MCU_Control.SchDoc | I2C_SCL contains IO Pin and Output Port objects (Pin U3-42, Port I2C_SCL).
Warning | BMS_CORE.SchDoc | Net B1_F has no driving source (Pin C14-2, Pin R8-2, Pin U4-16)
Warning | BMS_CORE.SchDoc | Net B2_F has no driving source (Pin C15-2, Pin R9-2, Pin U4-15)
Warning | BMS_CORE.SchDoc | Net B3_F has no driving source (Pin C16-2, Pin R10-2, Pin U4-14)
Warning | BMS_CORE.SchDoc | Net B4_F has no driving source (Pin C17-2, Pin R11-2, Pin U4-13)
Warning | Main_MPPT.SchDoc | Net BAT_N_F has no driving source (Pin C13-2, Pin R7-2, Pin R16-2, Pin R18-2, Pin
| | U4-17)
Warning | POWER_DISTRIBUTION.SchDoc Net NetC24_2 has no driving source (Pin C24-2, Pin U6-6)
Warning | POWER_DISTRIBUTION.SchDoc Net NetC27_1 has no driving source (Pin C27-1, Pin U7-2)
Warning | USB_DEBUG.SchDoc | Net NetIC1_9 has no driving source (Pin IC1-9, Pin R48-2)
Warning | POWER_DISTRIBUTION.SchDoc Net NetQ5_3 has no driving source (Pin Q5-3, Pin R32-2, Pin U7-1)
Warning | MCU_Control.SchDoc | Net NetR4_2 has no driving source (Pin R4-2, Pin U3-7)
Warning | BMS_CORE.SchDoc | Net NetR12_1 has no driving source (Pin R12-1, Pin U4-6)
Warning | POWER_DISTRIBUTION.SchDoc Net NetR19_1 has no driving source (Pin R19-1, Pin R20-1, Pin U5-4)
Warning | POWER_DISTRIBUTION.SchDoc Net NetR24_1 has no driving source (Pin R24-1, Pin R25-1, Pin U6-4)
Warning | POWER_DISTRIBUTION.SchDoc Net NetR33_2 has no driving source (Pin R33-2, Pin R34-2, Pin U7-3)
Warning | USB_DEBUG.SchDoc | Net USB_5Vhas no driving source (Pin CN1-A4, Pin CN1-A9, Pin CN1-B4, Pin CN1-B9,
| | Pin IC1-7, Pin IC1-8)
Warning | POWER_DISTRIBUTION.SchDoc NetC20_1 contains Input Pin and Unspecified Port objects (Pin U5-2, Pin U5-7, Pin U6-2,
| | Pin U6-7, Pin U7-8, Port SYS_VBAT, Port V12_SYS).
Warning | POWER_DISTRIBUTION.SchDoc NetC20_1 contains IO Pin and Unspecified Port objects (Pin U7-7, Port SYS_VBAT, Port
| | V12_SYS).
Warning | POWER_DISTRIBUTION.SchDoc NetC26_1 contains Unspecified Port and Output Sheet Entry objects (Port
| | VBOOST_OUT, Sheet Entry U_POWER_DISTRIBUTION-VBOOST_OUT(Output)).
Warning | MCU_Control.SchDoc | NetIC1_26 contains IO Pin and Output Pin objects (Pin U3-31, Pin IC1-26).
Warning | Main_MPPT.SchDoc | Nets Wire BAT_CHG_NODE has multiple names (Net Label BAT_CHG_NODE (3), Sheet
| | Entry U_POWER_SWITCH-CHG_IN(Input))
Warning | Main_MPPT.SchDoc | Nets Wire BAT_N has multiple names (Net Label BAT_N (12), Net Label S_P (2), Net
| | Label SYS_GND (13), Power Object SYS_GND (30), Sheet Entry
U_BMS_CORE-SENSE_P(Input)) Warning | Main_MPPT.SchDoc | Nets Wire BAT_N_F has multiple names (Net Label BAT_N_F (2), Sheet Entry
| | U_BMS_CORE-BAT_N(I/O), Sheet Entry U_POWER_SWITCH-BAT_N(I/O))
Warning | Main_MPPT.SchDoc | Nets Wire COMMON_NODE has multiple names (Net Label COMMON_NODE, Net
| | Label
| | SYS_VBAT (3), Net Label V12_SYS (3), Sheet Entry U_MCU_Control-SYS_VBAT(Input),
| | Sheet Entry U_OUTPUT_CONNECTORS-V12_SYS(Passive), Sheet Entry
| | U_POWER_DISTRIBUTION-SYS_VBAT(Passive), Sheet Entry
| | U_POWER_DISTRIBUTION-V12_SYS(Passive), Sheet Entry
| | U_POWER_SWITCH-SYS_VBAT(Output))
Warning | Main_MPPT.SchDoc | Nets Wire PV- has multiple names (Net Label PV- (5), Net Label S_N (2), Sheet Entry
| | U_BMS_CORE-SENSE_N(Input))
Warning | MCU_Control.SchDoc | NetU3_10 contains IO Pin and Input Port objects (Pin U3-10, Port BMS_ALERT).
Warning | MCU_Control.SchDoc | NetU3_30 contains IO Pin and Output Port objects (Pin U3-30, Port UART_TX).
Warning | MCU_Control.SchDoc | NetU3_31 contains IO Pin and Input Port objects (Pin U3-31, Port UART_RX).
Warning | USB_DEBUG.SchDoc | NRST contains Unspecified Port and Output Sheet Entry objects (Port NRST, Sheet Entry
| | U_USB_DEBUG-NRST(Output)).
Warning | POWER_SWITCH.SchDoc | Sheet contains duplicate ports Port 3V3_SYS at 91.04mm,35.24mm and
| | 91.04mm,57.24mm
Warning | POWER_SWITCH.SchDoc | Sheet contains duplicate ports Port BAT_N at 188.19mm,152.55mm and
| | 188.73mm,111.78mm
Warning | Main_MPPT.SchDoc | SYS_VBAT contains Input Sheet Entry and Unspecified Sheet Entry objects (Sheet Entry
Sunday 31 May 2026 10:51:00 PM | Page 1 of 2

Class | Document | Message
| | U_MCU_Control-SYS_VBAT(Input), Sheet Entry
| | U_POWER_DISTRIBUTION-SYS_VBAT(Passive)).
Warning | Main_MPPT.SchDoc | SYS_VBAT contains Output Sheet Entry and Unspecified Sheet Entry objects (Sheet
| | Entry U_POWER_SWITCH-SYS_VBAT(Output), Sheet Entry
U_POWER_DISTRIBUTION-SYS_VBAT(Passive)). Warning | Main_MPPT.SchDoc | V5_SYS contains Input Pin and Unspecified Sheet Entry objects (Pin U1-3, Sheet Entry
| | U_MCU_Control-V5_SYS(Passive), Sheet Entry
| | U_OUTPUT_CONNECTORS-V5_SYS(Passive), Sheet Entry
| | U_POWER_DISTRIBUTION-V5_SYS(Passive)).
Sunday 31 May 2026 10:51:00 PM | Page 2 of 2

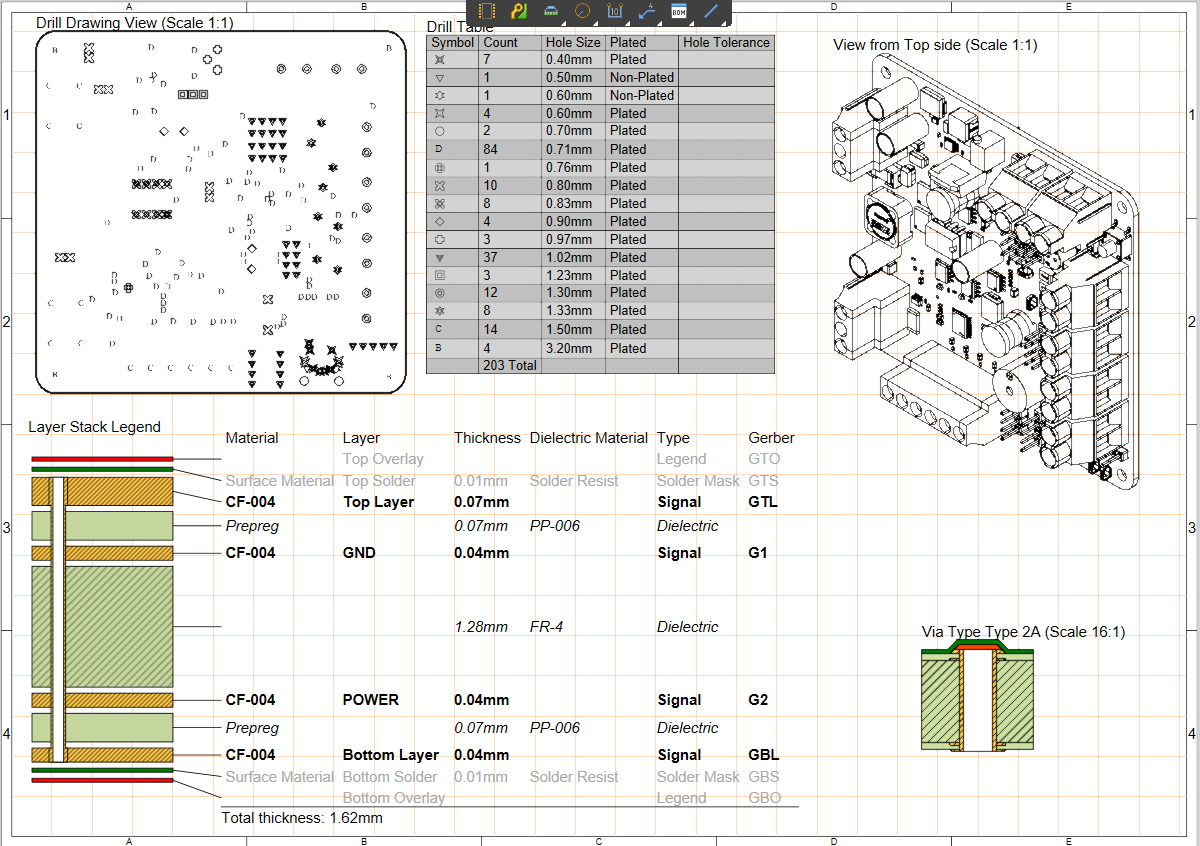
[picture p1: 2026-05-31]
Images/Screenshot 2026-05-30 160357.png

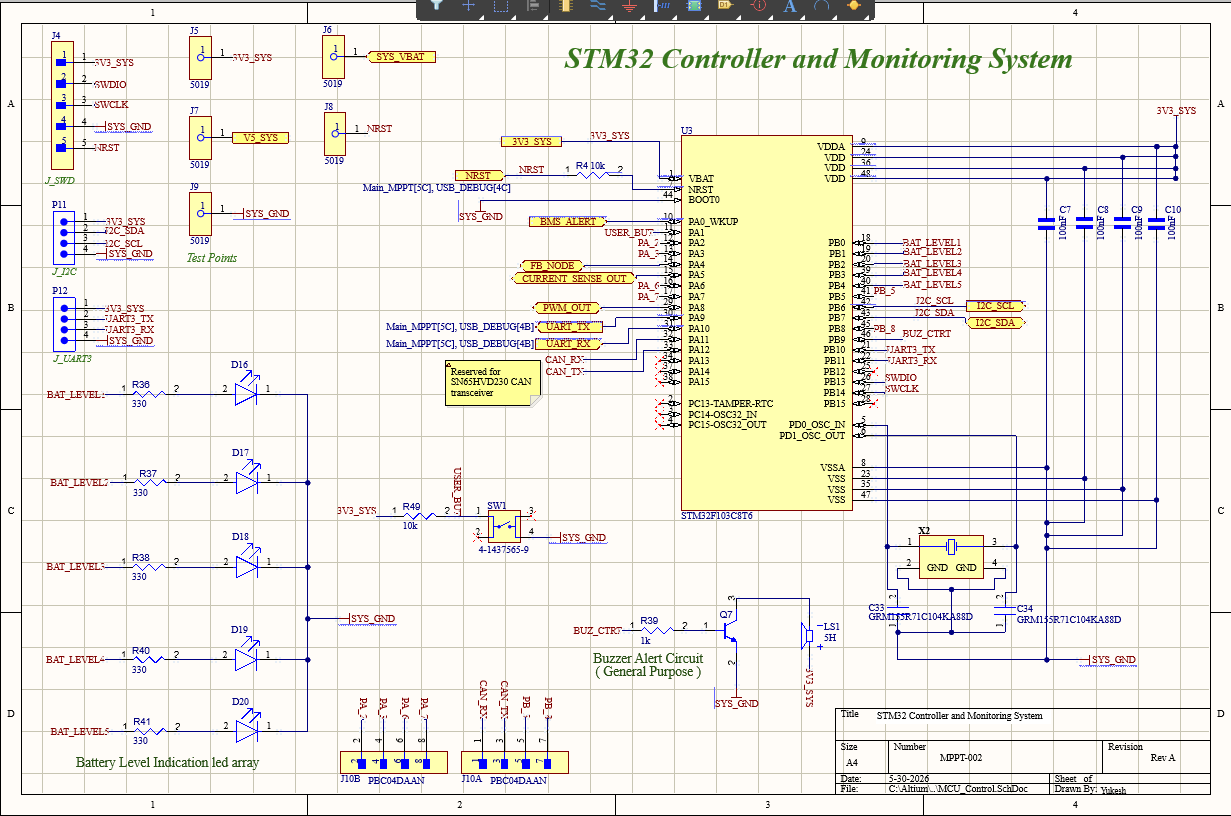
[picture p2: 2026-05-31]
Images/Screenshot 2026-05-30 160711.png

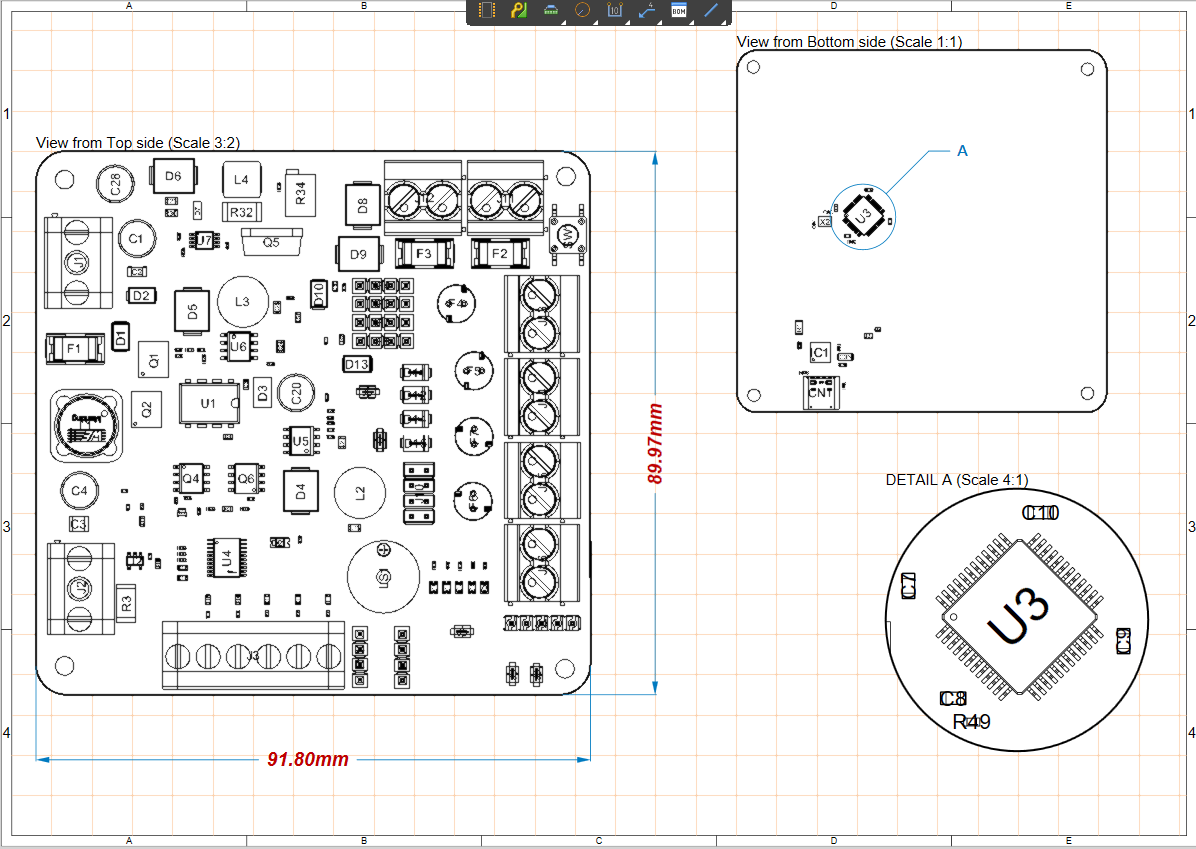
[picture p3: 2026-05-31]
Images/Screenshot 2026-05-30 160304.png

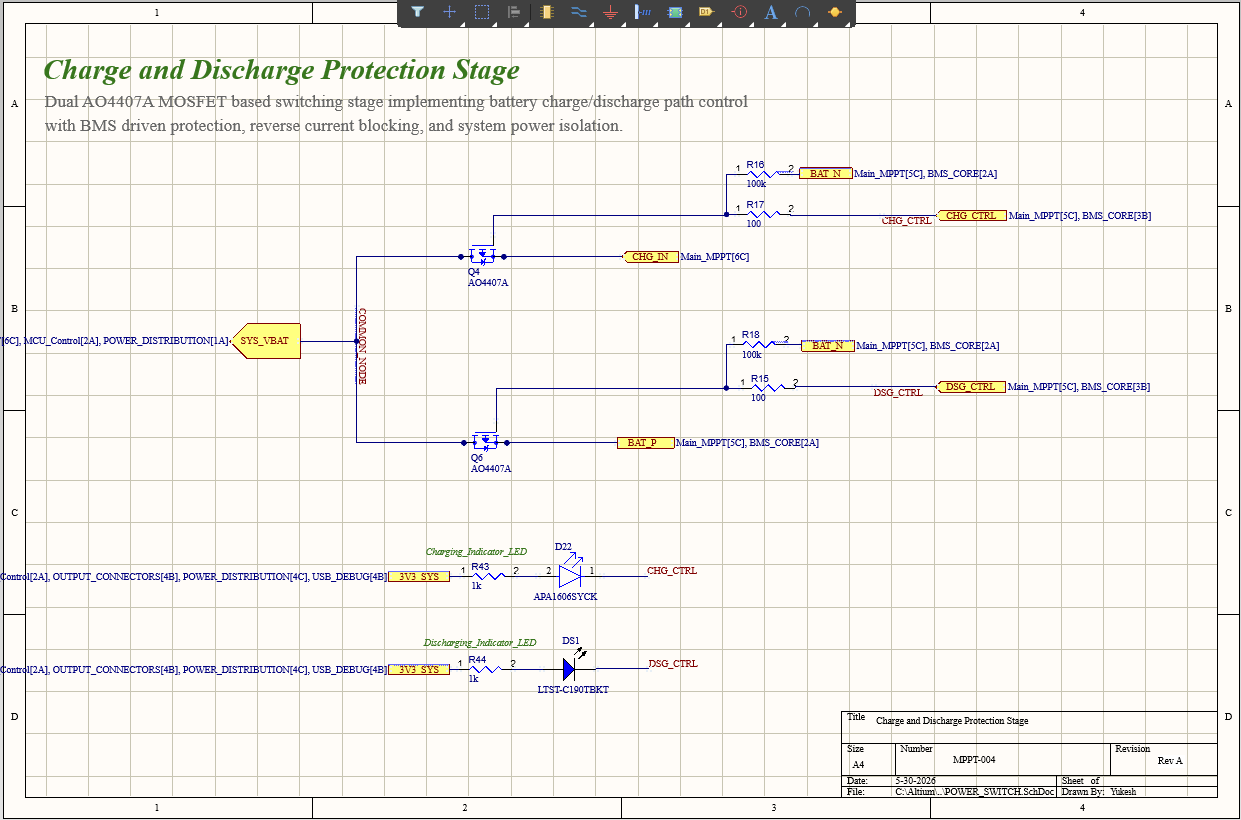
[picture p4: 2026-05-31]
Images/Screenshot 2026-05-30 160825.png

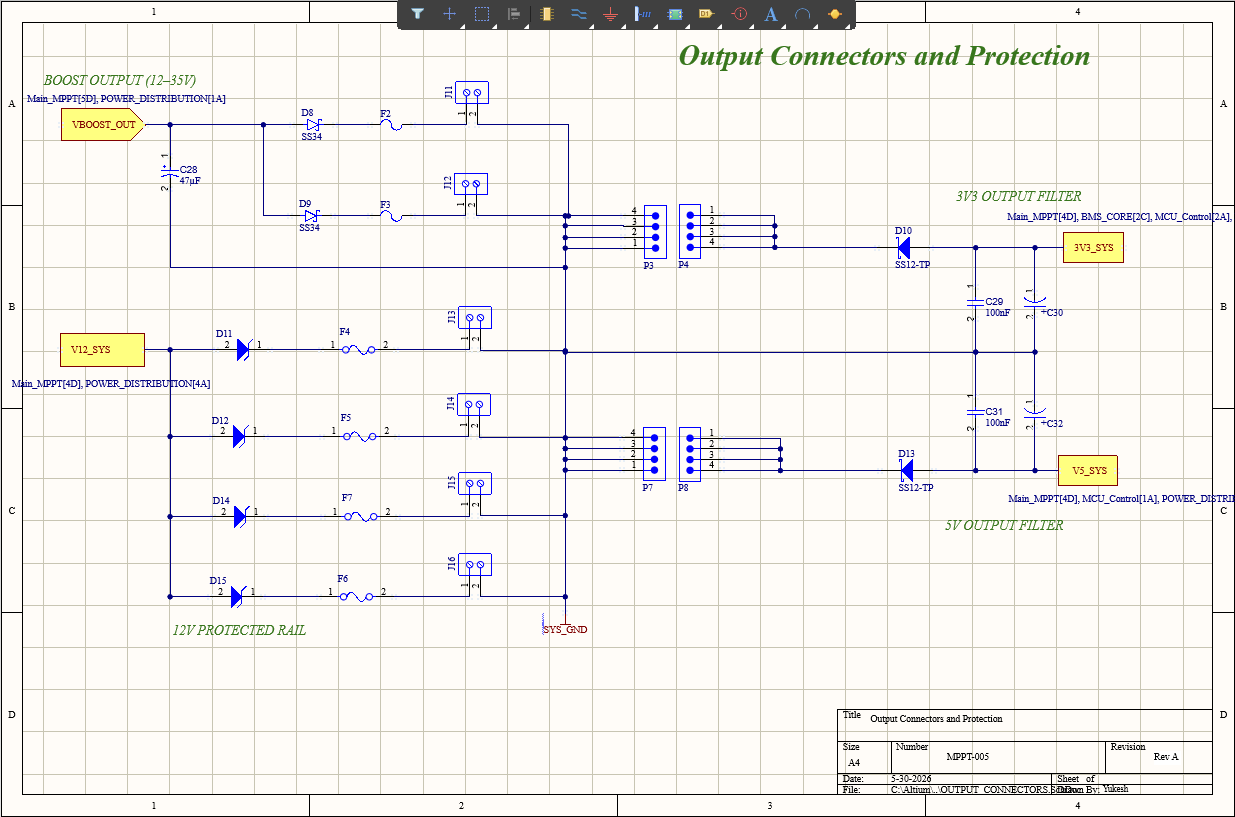
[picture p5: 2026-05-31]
Images/Screenshot 2026-05-30 160904.png

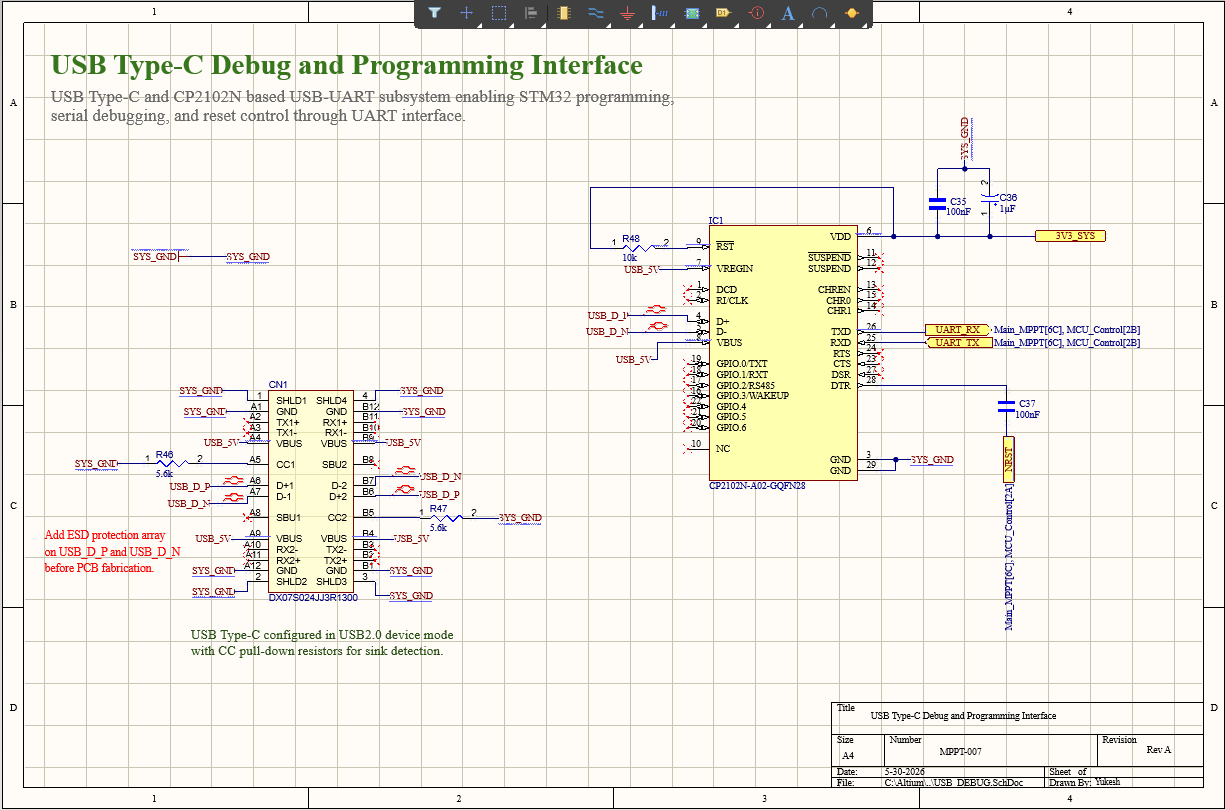
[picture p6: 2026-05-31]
Images/Screenshot 2026-05-30 161018.png

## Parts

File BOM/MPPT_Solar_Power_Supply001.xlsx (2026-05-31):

Line # | Name | Description | Designator | Quantity | Manufacturer 1 | Manufacturer Part Number 1 | Manufacturer Lifecycle 1 | Supplier 1 | Supplier Part Number 1 | Supplier Unit Price 1 | Supplier Subtotal 1
 | 1KR2J | 1K 0.063W 5% 0402 (1005 Metric) SMD | R22, R28, R42, R43, R44, R45 | 6
 | 1KR5J | 1K 0.125W 5% 0805 (2012 Metric) SMD | R30, R39 | 2
 | 4-1437565-9 | Alcoswitch, Switch, Tactile, 50 mA, SPST, Pushbutton, Off[On], FSM6JSMA | SW1 | 1
 | 4D7KR2F | 4K7 0.063W 1% 0402 (1005 Metric) SMD | R13, R14 | 2
 | 5D6KR2J | 5K6 0.063W 5% 0402 (1005 Metric) SMD | R46, R47 | 2
 | 10KR2F | 10K 0.063W 1% 0402 (1005 Metric) SMD | R12, R25, R26, R27, R48, R49 | 6
 | 10R2F | 10R 0.063W 1% 0402 (1005 Metric) SMD | R31 | 1
 | 22KR2F | 22K 0.063W 1% 0402 (1005 Metric) SMD | R33 | 1
 | 25D5KR2F | 25K5 0.063W 1% 0402 (1005 Metric) SMD | R20, R21 | 2
 | 100KR2F | 100K 0.063W 1% 0402 (1005 Metric) SMD | R1, R16, R18 | 3
 | 100R2F | 100R 0.063W 1% 0402 (1005 Metric) SMD | R5, R6, R7, R8, R9, R10, R11, R15, R17 | 9
 | 330R2J | 330R 0.063W 5% 0402 (1005 Metric) SMD | R36, R37, R38, R40, R41 | 5
 | 0603YC104KAZ2A | Capacitor MLCC 0603 100nF 16V | C5, C6, C7, C8, C9, C10, C11, C12, C13, C14, C15, C16, C17, C18, C19, C35, C37 | 17
 | 1714955 | PC Terminal Block, Pitch 6.35 mm, 1 x 2 Position, Height 21.5 mm, Tail Lenght 5.1 mm, RoHS, Bulk | J11, J12, J13, J14, J15, J16 | 6
 | 691244710006 | Terminal Block, 5MM Pitch, Horizontal, Rising Cage Clamp, 12-30 AWG, 6 Pin | J3 | 1
 | 691254810002 | Terminal Block, 10MM Pitch, Horizontal, Rising Cage Clamp, 12-30 AWG, 2 Pin | J1, J2 | 2
 | AO4407A | P-Channel 30 V 12A (Ta) 3.1W (Ta) Surface Mount 8-SOIC | Q4, Q6 | 2
 | C3216X7R1H106K160AE | 10 ÂµF Â±10% 50V Ceramic Capacitor X7R 1206 (3216 Metric) | C2 | 1
 | Capacitor 10nF +/-20% 50V 0402 | Chip Capacitor, 10nF +/-20%, 50V, 0402, Thickness 0.6 mm | C27 | 1
 | Capacitor 22µF +/-40% 16V 0805 | Chip Capacitor, 22µF +/-40%, 16V, 0805, Thickness 1.45 mm | C22, C23, C24, C25 | 4
 | Capacitor 47µF +/-40% 6.3V 0805 | Chip Capacitor, 47µF +/-40%, 6.3V, 0805, Thickness 1.45 mm | C26 | 1
 | Capacitor 100nF +/-20% 25V 0402 | Chip Capacitor, 100nF +/-20%, 25V, 0402, Thickness 0.6 mm | C29, C31 | 2
 | Capacitor 100nF +/-20% 50V 0402 | Chip Capacitor, 100nF +/-20%, 50V, 0402, Thickness 0.6 mm | C21 | 1
 | CMI-1210-5-95T | 12 mm, 5 Vdc, 98 dB, Through Hole, Magnetic Audio Indicator Buzzer | LS1 | 1
 | CP2102N-A02-GQFN28 | USB TO UART BRIDGE, -40 TO 85DEG C; Bridge Type:USB to UART; Supply Voltage Min:3V; Supply Voltage Max:3.6V; Interface Case Style:QFN; No. of Pins:28Pins; Operating Temperature Min:-40Â°C; Operating Temperature Max:85Â°C; Product Range:-; Automotive Quali | IC1 | 1
 | CSD18540Q5BT | 60-V, N channel NexFETâ„¢ power MOSFET, single SON 5 mm x 6 mm, 2.2 mOhm | Q1, Q2 | 2
 | DX07S024JJ3R1300 | USB-C Connector, 20 V, 1.25 A, -30 to 80 degC, RoHS, Tape and Reel | CN1 | 1
 | ECA1HM470 | Aluminum Electrolytic Capacitor, 47 uF, +/- 20%, 50 V, -40 to 85 degC, 2-Pin THD, RoHS, Bulk | C1, C4, C20, C28 | 4
 | ERJ2RHD2702X | ERJ2R Resistor 0.063W 27K 0.5% 50ppm | R2, R35 | 2
 | ETQP4M330YFN | FIXED IND 33UH 2.5A 189.2MOHM SM | L4 | 1
 | F980J106MMA | CAP TANT 10UF 20% 6.3V 0603 | C30, C32 | 2 | Nichicon | F980J106MMA
 | GRM32ER71E226KE15L | SMD capacitor X7R(EIA) with capacitance 22uF Tol.10%. Rated voltage 25Vdc 125C | C3 | 1
 | HSMG-C190 | LED Uni-Color Green, 52 mW, 20 mA, -40 to 85 degC, 2-Pin SMD, RoHS, Tape and Reel | DS2 | 1
 | INA180A1IDBVT | 26V, 350kHz ì „ë¥˜ ê° ì§€ ì | U2 | 1
 | IR2104 | Half-Bridge Gate Driver IC Non-Inverting 8-PDIP | U1 | 1
 | IRLZ44N | N-Channel 55 V 47A (Tc) 3.8W (Ta), 110W (Tc) Surface Mount D2PAK | Q5 | 1
 | LM3478MM | 2.97~40V Wide Input Range Boost/SEPIC/Flyback DC-DC Controller | U7 | 1
 | MMBT2222AM3T5G | NPN General Purpose Transistor, 3-Pin SOT-723, Pb-Free, Tape and Reel | Q7 | 1
 | MP1584EN | Buck Switching Regulator IC Positive Adjustable 0.8V 1 Output 3A 8-SOIC (0.154, 3.90mm Width) Exposed Pad | U5, U6 | 2
 | PBC04DAAN | CONN HEADER VERT 8POS 2.54MM | J10 | 1
 | Resistor 10K +/-1 % 0402 63 mW | Chip Resistor, 10 kOhms, +/-1 %, 63 mW, -55 to 125 degC, 0402 | R19, R23, R24, R29 | 4
 | Resistor 10k +/-1% 1206 250 mW | Chip Resistor, 10 KOhm, +/- 1%, 0.25 W, -55 to 155 degC, 1206 (3216 Metric) | R4 | 1
 | RL622-100K-RC | Radial Inductor, 10 uH, +/- 10%, 3 A, -55 to 105 degC, 2-Pin THD, RoHS, Bulk | L2, L3 | 2
 | SMAJ33A | 400W, 38.7V, 5%, Unidirectional, TVS | D2 | 1
 | SS14 | 1A, 40V, Schottky Rectifier | D3 | 1
 | SS34 | Diode Schottky 40 V 3A Surface Mount SMC (DO-214AB) | D4, D5, D6, D8, D9 | 5
 | STM32F103C8T6 | ARM® Cortex®-M3 STM32F1 Microcontroller IC 32-Bit 72MHz 64KB (64K x 8) FLASH 48-LQFP (7x7) | U3 | 1
 | T63XB503KT20 | T63 XB 50K 10% TU e3 | R34 | 1
 | TAJA105K035RNJ | Standard Tantalum, 1 uF, +/- 10%, 35 V, -55 to 125 degC, 1206 (3216 Metric), RoHS, Tape and Reel | C36 | 1
 | TSX-3225 24.0000MF15X-AC3 | MHz Range Crystal, 24 MHz, -40 to 85 degC, 4-Pin SMD, RoHS, Tape and Reel | X2 | 1 | Epson | TSX-322524.0000MF15X-AC3
 | WE-PD_1260 | Power inductor SMD WE-PD L 10.0uH 4.09A | L1 | 1
 | WSL2512R0100FEA18 | METAL STRIP RESISTOR, 0.01OHM, 1%, 2512; Resistance: 0.01ohm; Product Range: WSL High Power Series; Resistor Case / Package: 2512 ^6432 Metric]; Power Rating: 2W; Resistance Tolerance: ± 1%; Resistor Techn 18X4752 | R3, R32 | 2
 | 5019 | Phosphor Bronze Contact Miniature Silver Plated Surface Mount Test Points | J5, J6, J7, J8, J9 | 5 | Keystone | 5019 | Volume Production | DigiKey | 36-5019DKR-ND | 22.9 | 114.48
 | SML-LX0805UWC-TR | SML-LX0805UWC-TR White LED, 0805 Diffused, Rectangle Lens SMD package | D16, D17, D18, D19, D20 | 5 | Lumex | SML-LX0805UWC-TR | Volume Production | DigiKey | 67-SML-LX0805UWC-TRDKR-ND | 167.9 | 839.52
 | GRM155R71C104KA88D | CAP CER 0.1UF 16V X7R 0402 | C33, C34 | 2 | Murata | GRM155R71C104KA88D | Not Recommended for New Design | Mouser | 81-GRM155R71C104KA88 | 1.43 | 14.31
 | LTST-C190TBKT | Single Color Chip LED, 2.8 to 3.8 V, 28 to 180 mcd, -20 to 80 degC, 2-Pin SMD, RoHS, Tape and Reel | DS1 | 1 | Diodes Inc. | LTST-C190TBKT | Volume Production | DigiKey | 160-1646-6-ND | 16.22 | 16.22
 | BQ7692000PWR | IC BATT MON MULTI 3-5C 20TSSOP | U4 | 1 | Texas Instruments | BQ7692000PWR | Volume Production | DigiKey | 296-39958-1-ND | 350.12 | 350.12
 | 824500600 | TVS diode [Würth Elektronik] 824500600 TVS diode | D11, D12, D14, D15 | 4 | Wurth Elektronik | 824500600 | Volume Production | DigiKey | 732-SMAJ6.0ATR-ND | 17.08 | 17076.53
 | SS12-TP | Schottky Rectifier, 20 V, 1 A, -55 to 125 degC, 2-Pin DO-214AC, RoHS, Tape and Reel | D1, D10, D13 | 3 | MCC | MBR0530-TP | Volume Production | Mouser | 833-MBR0530-TP | 14.31 | 42.93
 | 0154001.DR | Very Fast-Acting Fuse, 1 A, -55 to 125 degC, 2-Pin SMD, RoHS, Tape and Reel | F1, F2, F3 | 3 | Littelfuse | 0154001.DR | Volume Production | RS (Formerly Allied Electronics) | 0154001.DR | 93.49 | 280.47
 | 02810005H | FUSE HLDR RADIAL 125V 5A PNL MNT | F4, F5, F6, F7 | 4 | Littelfuse | 02810005H | Volume Production | Arrow Electronics | 02810005H | 304.23 | 1216.92
 | 22-28-4050 | 22-28-4050 KK® 254 Breakaway Header, Vertical, 5 Circuits, Tin (Sn) Plating, Mating Pin Length 6.09mm | J4 | 1 | Molex | 22-28-4050 | Volume Production | Arrow Electronics | 0022284050 | 8.97 | 8.97
 | APA1606SYCK | LED YELLOW CLEAR CHIP SMD R/A | D22 | 1 | Kingbright | APA1606SYCK | Volume Production | RS (Formerly Allied Electronics) | APA1606SYCK | 7.63 | 7.63
 | BZX84C47LT1G | Zener Voltage Regulator, 225 mW, 3-Pin SOT-23, Pb-Free, Tape and Reel | D7 | 1 | onsemi | BZX84C47LT1G | Volume Production | Arrow Electronics | BZX84C47LT1G | 14.07 | 14.07
 | LTST-C230EKT | LED RED CLEAR CHIP SMD | D21 | 1 | Lite-On | LTST-C230EKT | Volume Production | Arrow Electronics | LTST-C230EKT | 3.26 | 3.26
 | TSW-104-08-G-S | 0.025" SQ Post Header, Through-hole, Vertical, -55 to 125 degC, 2.54 mm Pitch, 4-Pin, Male, RoHS | P3, P4, P7, P8, P11, P12 | 6 | Samtec | TSW-104-08-G-S | Volume Production | Avnet | TSW-104-08-G-S | 71.05 | 426.32

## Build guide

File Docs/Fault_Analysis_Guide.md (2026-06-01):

# Fault Analysis Guide

## Overview

This document describes the potential fault conditions that may occur within the SolarCore-4S MPPT Power Management System and provides guidance for detection, diagnosis, user notification, and corrective actions.

The fault management architecture combines:

- BQ76920 Battery Protection
- STM32 Monitoring Firmware
- Current Sensing
- Voltage Monitoring
- LED Indicators
- Audible Alerts

---

# Fault Classification

Faults are categorized into four groups:

| Category | Description |
|---|---|
| Battery Faults | Cell voltage and battery protection events |
| Charging Faults | Charge path abnormalities |
| System Faults | Internal hardware or firmware issues |
| Communication Faults | Interface and peripheral failures |

---

# Fault Detection Sources

| Source | Monitored Parameters |
|---|---|
| BQ76920 | Cell Voltages, OVP, UVP, OCP |
| INA180 | Charge Current |
| ADC Measurements | System Voltage |
| STM32 Firmware | Communication, Logic Checks |
| Future PV Sense Circuit | Solar Panel Voltage |

---

# Battery Protection Faults

## Cell Overvoltage

### Detection Source

BQ76920

### Cause

- Excessive charging voltage
- Charger malfunction
- Incorrect battery configuration

### System Response

- Disable charging MOSFET
- Assert BMS_ALERT
- Trigger fault indication

### User Indication

LED Pattern:

```text
All LEDs Blink Fast
```

Buzzer:

```text
Long Continuous Tone
```

### Corrective Action

- Disconnect charger
- Verify battery pack voltage
- Inspect charging circuitry

---

## Cell Undervoltage

### Detection Source

BQ76920

### Cause

- Deep battery discharge
- Excessive load
- Battery aging

### System Response

- Disable discharge MOSFET
- Prevent further battery drain

### User Indication

LED Pattern:

```text
LED1 Fast Blink
```

Buzzer:

```text
Short Beep Every 2 Seconds
```

### Corrective Action

- Recharge battery immediately
- Check connected loads

---

## Charge Overcurrent

### Detection Source

BQ76920

### Cause

- Excessive charging current
- Charger malfunction
- Shorted battery cell

### System Response

- Disable charging path

### User Indication

Charging LED:

```text
Fast Blink
```

Buzzer:

```text
Double Long Beep
```

### Corrective Action

- Verify charging source
- Inspect battery condition

---

## Discharge Overcurrent

### Detection Source

BQ76920

### Cause

- Load overload
- Output short circuit

### System Response

- Disable discharge path
- Protect battery

### User Indication

LED Pattern:

```text
Alternating LED Flash
```

### Corrective Action

- Remove load
- Inspect output connectors

---

# Battery Connection Faults

## Battery Missing

### Detection Source

Firmware

### Cause

- Battery disconnected
- Loose terminal connection

### System Response

- Disable charging
- Disable discharge

### User Indication

LED Pattern:

```text
LED1 and LED5 Blink
```

### Corrective Action

- Verify battery wiring
- Check connector integrity

---

## Cell Tap Wiring Fault

### Detection Source

BQ76920 Cell Voltage Monitoring

### Cause

- Incorrect battery harness wiring
- Open cell tap connection

### System Response

- Enter protection mode

### User Indication

LED Pattern:

```text
Sequential Flash Pattern
```

### Corrective Action

- Verify B1–B4 connections
- Check battery harness

---

# Charging System Faults

## Solar Input Missing

### Detection Source

Firmware Voltage Measurement

### Cause

- No solar input
- PV connector disconnected

### System Response

- Disable charging state

### User Indication

Charging LED OFF

### Corrective Action

- Verify solar panel connection
- Measure PV voltage

---

## PV Voltage Sense Not Available

### Detection Source

Firmware

### Cause

Current Revision A limitation.

### Description

The current PCB revision reserves PA3 for future photovoltaic voltage measurement but does not directly acquire PV panel voltage.

### System Impact

- Basic charging operation unaffected
- Advanced MPPT optimization unavailable

### Future Solution

Use external voltage divider connected to reserved PV sensing interface.

---

# Current Measurement Faults

## Current Sensor Failure

### Detection Source

ADC Monitoring

### Signal

PA5

### Cause

- INA180 failure
- Open sense path
- PCB damage

### System Response

- Disable MPPT algorithm
- Raise warning flag

### User Indication

LED2 + LED4 Blink

### Corrective Action

- Inspect INA180
- Verify shunt resistor

---

## Invalid Current Reading

### Detection Source

Firmware Validation

### Cause

- ADC corruption
- Sensor saturation
- Noise

### System Response

- Ignore measurement
- Raise warning

---

# Voltage Measurement Faults

## Feedback Voltage Out of Range

### Detection Source

PA4 ADC

### Cause

- Divider resistor failure
- Wiring issue
- Unexpected battery voltage

### System Response

- Disable MPPT control

### User Indication

LED1 + LED3 + LED5 Blink

---

# Communication Faults

## BQ76920 Communication Failure

### Detection Source

I²C Timeout

### Interface

PB5 (SCL)
PB6 (SDA)

### Cause

- I²C bus failure
- BQ76920 fault
- Pull-up resistor issue

### System Response

- Disable charging
- Disable discharge
- Raise critical fault

### User Indication

LED Pattern:

```text
LED1 + LED3 + LED5 Blink
```

Buzzer:

```text
Three Short Pulses
```

### Corrective Action

- Verify SDA/SCL lines
- Check BQ76920 power supply

---

## UART Communication Failure

### Detection Source

Firmware

### Interfaces

UART1
UART3

### Cause

- Disconnected peripheral
- ESP32 not responding
- USB connection lost

### System Response

- Log warning
- Continue operation

### Severity

Low

---

# MCU Faults

## Watchdog Reset

### Detection Source

Firmware

### Cause

- Software lockup
- Unexpected execution state

### System Response

- Automatic restart

### User Indication

Startup sequence repeats

### Corrective Action

- Review firmware logs

---

## Brownout Event

### Detection Source

STM32 Reset Flags

### Cause

- Supply voltage collapse
- Excessive load

### System Response

- Safe restart

### User Indication

Double startup beep

---

# Future Thermal Faults

## Overtemperature

### Status

Not Implemented in Revision A

### Reserved Expansion

PA6
PA7

### Potential Sensors

- NTC Thermistor
- Digital Temperature Sensor

### Planned Response

- Reduce charging current
- Disable outputs
- Alert user

---

# Fault Severity Levels

| Level | Description | Action |
|---|---|---|
| INFO | Informational Event | Log Only |
| WARNING | Minor Issue | User Notification |
| MAJOR | System Degradation | Protective Action |
| CRITICAL | Safety Risk | Immediate Shutdown |

---

# Recommended Fault Codes

| Code | Description |
|---|---|
| F001 | Cell Overvoltage |
| F002 | Cell Undervoltage |
| F003 | Charge Overcurrent |
| F004 | Discharge Overcurrent |
| F005 | Battery Missing |
| F006 | Cell Tap Fault |
| F007 | Current Sensor Failure |
| F008 | Feedback Voltage Error |
| F009 | BQ76920 Communication Failure |
| F010 | Brownout Reset |
| F011 | Watchdog Reset |
| F012 | Thermal Fault (Future) |

---

# Revision Information

Document Version: 1.0

Applicable Hardware Revision: Rev A

Board:

SolarCore-4S MPPT Power Management System

Author:

Yukesh S

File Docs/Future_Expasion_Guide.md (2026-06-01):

# Future Expansion Guide

## Overview

The SolarCore-4S MPPT Power Management System was intentionally designed with future expansion capability in mind.

Several hardware resources, communication interfaces, GPIOs, and reserved MCU peripherals remain available for future firmware and hardware upgrades.

This document outlines potential development paths beyond Hardware Revision A.

---

# Expansion Philosophy

The primary objective of Revision A was to establish a stable hardware platform containing:

- Battery Management
- Power Distribution
- Embedded Control
- Communication Interfaces
- Development Interfaces

Future revisions can build upon this foundation without requiring a complete hardware redesign.

---

# Expansion Categories

Future development opportunities are divided into:

1. User Interface Expansion
2. Communication Expansion
3. Energy Harvesting Expansion
4. Data Logging Expansion
5. Industrial Interface Expansion
6. Smart Power Management Expansion
7. Cloud Connectivity Expansion
8. Advanced Battery Analytics

---

# OLED Display Integration

## Current Hardware Support

The board already provides an I²C interface.

### STM32 Connections

| Signal | STM32 Pin |
|---|---|
| SDA | PB6 |
| SCL | PB5 |

---

## Recommended Display

SSD1306 OLED

### Resolution

```text
128 × 64
```

---

## Potential Display Pages

### Home Screen

```text
Battery Voltage
Battery Percentage
Charging Status
System Status
```

---

### Battery Screen

```text
Cell 1 Voltage
Cell 2 Voltage
Cell 3 Voltage
Cell 4 Voltage
```

---

### Solar Screen

```text
PV Voltage
PV Current
PV Power
```

Requires future PV voltage sensing implementation.

---

### Fault Screen

```text
Fault Code
Fault Description
System State
```

---

### Debug Screen

```text
ADC Values
UART Status
BMS Status
PWM Duty Cycle
```

---

# ESP32 Integration

## Current Hardware Support

UART3 Interface

| Signal | STM32 Pin |
|---|---|
| TX | PB10 |
| RX | PB11 |

---

## Potential ESP32 Features

### WiFi Dashboard

Display:

- Battery Information
- Solar Statistics
- Fault Information
- Charging State

Accessible from:

- Mobile Phone
- Tablet
- Laptop

---

### MQTT Support

Potential Topics:

```text
battery/voltage
battery/soc
battery/status
system/fault
solar/power
```

---

### Home Assistant Integration

Possible Sensors:

- Battery Voltage
- Battery Percentage
- Charging State
- Fault Status
- Solar Power

---

### OTA Firmware Updates

Future architecture may allow:

- Wireless firmware distribution
- Remote maintenance
- System upgrades

---

# Bluetooth Expansion

Possible Hardware:

- ESP32
- HC-05
- HM-10

Potential Features:

- Mobile Application
- Live Battery Data
- Configuration Interface
- Fault Notifications

---

# LoRa Communication

Potential Hardware:

- SX1278
- RA-02

Applications:

- Remote Solar Systems
- Agricultural Installations
- Off-Grid Monitoring
- Long Distance Telemetry

---

# GSM Connectivity

Potential Modules:

- SIM800L
- SIM7600

Possible Features:

- SMS Alerts
- Remote Monitoring
- Cloud Upload
- GPS Tracking

---

# CAN Bus Expansion

## Reserved MCU Resources

| Signal | STM32 Pin |
|---|---|
| CAN_TX | PA11 |
| CAN_RX | PA12 |

---

## Required Hardware

Future Revision:

```text
CAN Transceiver
```

Examples:

- TJA1050
- MCP2551
- SN65HVD230

---

## Potential Applications

### Industrial Systems

- Battery Cabinets
- Energy Storage Systems
- Distributed Power Systems

---

### Vehicle Systems

- Solar Vehicles
- Electric Vehicles
- Utility Monitoring

---

### Smart Energy Networks

- Multiple Battery Packs
- Distributed Controllers
- Central Monitoring

---

# Advanced MPPT Implementation

## Current Limitation

Revision A does not directly measure photovoltaic panel voltage.

---

## Reserved Resource

| STM32 Pin |
|----------|
| PA3 |

---

## Future Hardware

External voltage divider interface.

---

## Future Capabilities

### Real-Time PV Voltage Monitoring

```text
PV Voltage
PV Current
PV Power
```

---

### True MPPT Algorithms

Potential Algorithms:

#### Perturb and Observe

Advantages:

- Simple
- Low computation cost

---

#### Incremental Conductance

Advantages:

- Faster tracking
- Better dynamic response

---

#### Adaptive MPPT

Advantages:

- Improved efficiency
- Reduced oscillation

---

# Temperature Monitoring

## Available MCU Resources

| Pin |
|------|
| PA6 |
| PA7 |

---

## Potential Sensors

### NTC Thermistor

Applications:

- Battery Temperature
- MOSFET Temperature
- PCB Temperature

---

### Digital Sensors

Examples:

- DS18B20
- TMP102
- LM75

---

## Future Firmware Features

- Thermal Protection
- Fan Control
- Charge Current Derating
- Thermal Logging

---

# Smart Cooling System

Future capability using reserved GPIOs.

Potential Features:

- Automatic Fan Control
- Thermal Regulation
- Power Stage Cooling

Control Inputs:

```text
Battery Temperature
MOSFET Temperature
PCB Temperature
```

---

# Data Logging

## Internal Logging

Possible Data:

- Battery Voltage
- Current
- Fault Events
- Charging Sessions

---

## External EEPROM

Via I²C Interface

Potential Devices:

- 24LC256
- AT24C512

---

## SD Card Logging

Future Hardware Revision

Potential Data:

```text
Timestamp
Battery Voltage
Current
Power
Fault Events
```

---

# Advanced Battery Analytics

Future Features:

### State of Charge

SOC Calculation

---

### State of Health

SOH Estimation

---

### Cycle Counting

Battery Lifetime Tracking

---

### Runtime Prediction

Estimated Remaining Capacity

---

# Smart Output Management

Future firmware may implement:

### Load Prioritization

Priority 1:

Critical Loads

Priority 2:

Normal Loads

Priority 3:

Non-Critical Loads

---

### Low Battery Load Shedding

Automatically disconnect:

- Non-essential loads
- Auxiliary systems

Preserve:

- Critical equipment

---

# User Interface Expansion

## Additional Buttons

Potential Features:

- Menu Navigation
- Settings Access
- Diagnostic Mode

---

## RGB Status LED

Potential States:

- Normal Operation
- Charging
- Fault
- Low Battery

---

# Mobile Application

Future ESP32 integration may support:

### Android Application

Features:

- Battery Monitoring
- Charging Status
- Fault Notifications
- Historical Data

---

### iOS Application

Features:

- Live Dashboard
- System Monitoring
- Alerts

---

# Cloud Connectivity

Future possibilities:

### MQTT Broker

### ThingsBoard

### Blynk

### AWS IoT

### Azure IoT

### Home Assistant

---

# Future Hardware Revision Roadmap

## Revision B

- PV Voltage Sensing
- Basic MPPT Implementation

---

## Revision C

- OLED Dashboard
- Advanced UI

---

## Revision D

- ESP32 Telemetry
- Wireless Monitoring

---

## Revision E

- CAN Interface
- Industrial Connectivity

---

## Revision F

- Data Logging
- SD Card Storage

---

## Revision G

- Cloud Platform
- Mobile Applications

---

# Long-Term Vision

The long-term objective is to evolve the SolarCore-4S platform into a complete embedded energy management system capable of:

- Solar Energy Harvesting
- Intelligent Battery Management
- Remote Monitoring
- Industrial Communication
- Wireless Connectivity
- Data Analytics
- Cloud Integration

while maintaining compatibility with the original hardware architecture.

---

## Revision Information

Document Version: 1.0

Board Revision: Rev A

Project:

SolarCore-4S MPPT Power Management System

Author:

Yukesh S

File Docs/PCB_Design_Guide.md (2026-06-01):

# PCB Design Guide

## Overview

This document describes the PCB design methodology, layout strategy, stackup selection, grounding architecture, routing decisions, thermal considerations, and manufacturing preparation for the SolarCore-4S MPPT Power Management System.

The PCB was developed using Altium Designer and follows professional PCB design practices for mixed-signal embedded power electronics systems.

The board integrates:

- Battery Management
- Embedded Control
- Power Distribution
- Communication Interfaces
- Future MPPT Capability
- Expansion Interfaces

---

# Design Objectives

The PCB was designed with the following goals:

- Reliable power distribution
- Low-noise analog measurements
- Future firmware expansion
- Modular subsystem organization
- Manufacturing readiness
- Professional documentation generation

---

# PCB Information

| Parameter | Value |
|---|---|
| Design Tool | Altium Designer |
| Layer Count | 4 |
| PCB Type | Mixed Signal |
| MCU | STM32F103C8T6 |
| BMS IC | BQ76920 |
| USB Interface | CP2102N |
| Power Architecture | Battery Management and Power Distribution |
| Documentation | Draftsman |

---

# PCB Images

## Top View
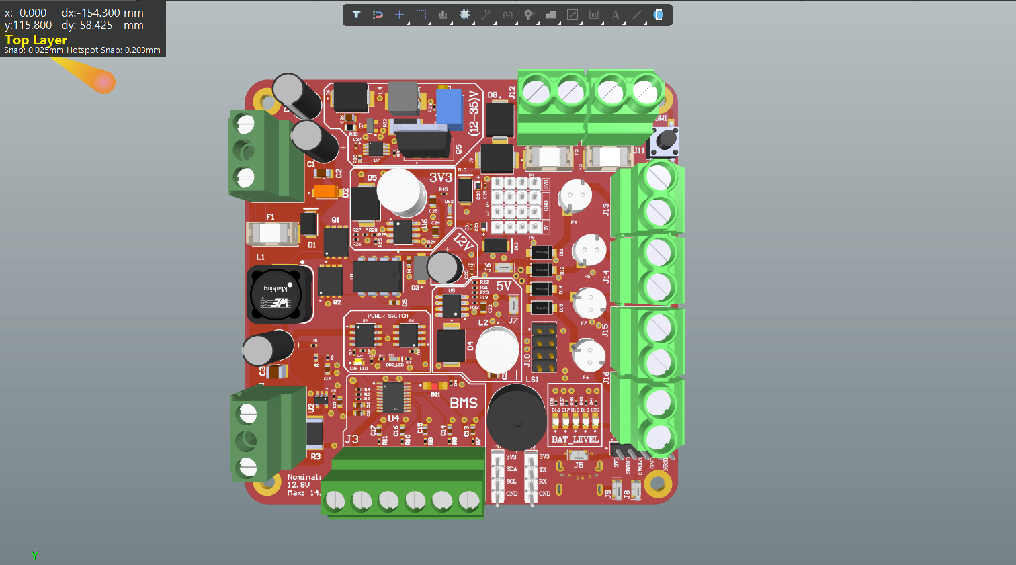
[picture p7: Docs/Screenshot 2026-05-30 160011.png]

Description:

Top layer contains the majority of active components including:

- STM32 Controller
- BQ76920
- Power Conversion Components
- Protection Circuitry
- USB-C Interface
- Expansion Headers

---

## Bottom View
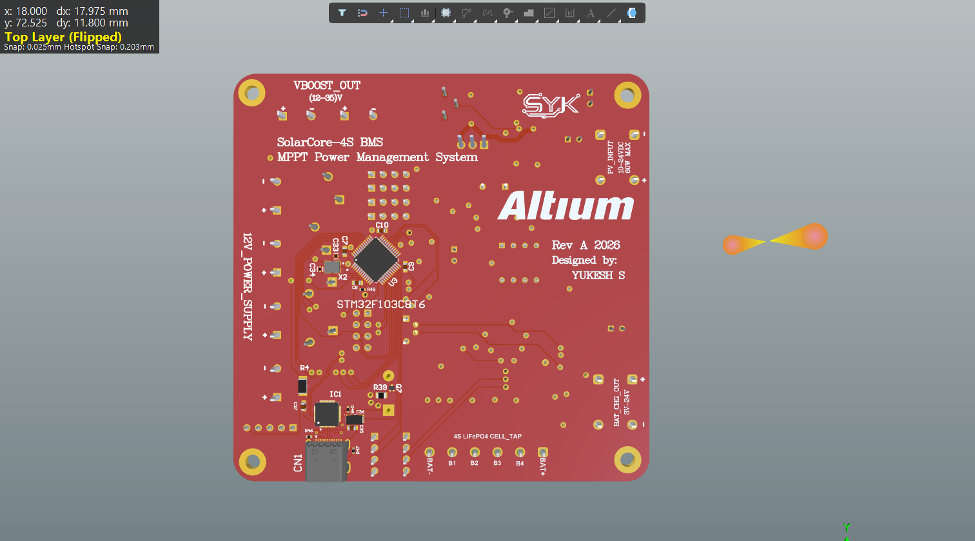
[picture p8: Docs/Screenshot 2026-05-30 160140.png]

Description:

Bottom layer primarily supports:

- Signal Routing
- Plane Connections
- Thermal Via Connections
- Power Distribution Support

---

## Perspective View
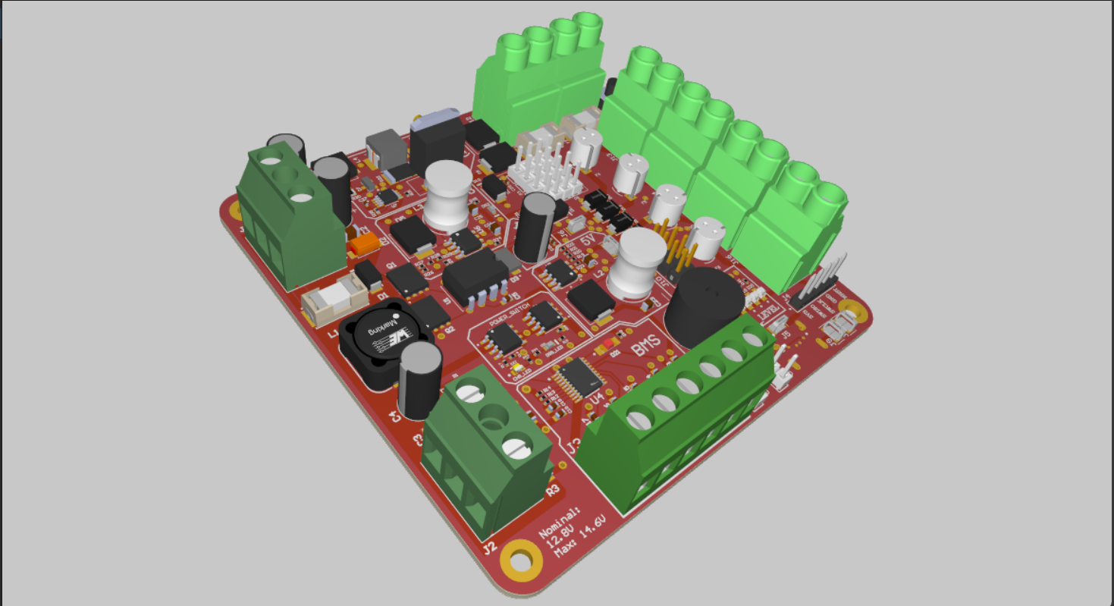
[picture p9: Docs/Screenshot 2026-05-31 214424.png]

Description:

The 3D view demonstrates final component placement, connector accessibility, and overall mechanical organization.

---

# Layer Stackup

## Layer 1

### Top Signal Layer

Contains:

- Component placement
- Critical signal routing
- Power routing
- High-density interconnects

---

## Layer 2

### Ground Plane

Dedicated ground plane.

Purpose:

- Low impedance return path
- Noise reduction
- Improved signal integrity
- EMI reduction

---

## Layer 3

### Power Plane

Used for:

- Battery power distribution
- Regulated voltage rails
- Internal power routing

Benefits:

- Reduced voltage drop
- Simplified routing
- Improved current handling

---

## Layer 4

### Bottom Signal Layer

Used for:

- Secondary routing
- Interface signals
- Expansion routing
- Support traces

---

# Placement Strategy

The PCB follows a functional block placement methodology.

Subsystems are grouped according to function.

---

# STM32 Control Section

The STM32 subsystem is located in a dedicated control area.

Components:

- STM32F103C8T6
- Decoupling capacitors
- Crystal oscillator
- Reset circuitry
- Programming interface

Design Goals:

- Minimize digital noise
- Short decoupling paths
- Clean routing environment

---

# Battery Management Section

The BQ76920 subsystem is placed close to battery monitoring circuitry.

Design Goals:

- Accurate cell measurements
- Reduced noise pickup
- Short sensing paths

Benefits:

- Improved voltage monitoring
- Reliable fault detection

---

# Charge and Discharge Protection

Protection MOSFETs are grouped together.

Purpose:

- Simplified current flow
- Thermal management
- Easier troubleshooting

---

# USB-C Interface Placement

The USB-C connector is placed near the PCB edge.

Benefits:

- Easy accessibility
- Convenient firmware development
- Improved mechanical usability

---

# Expansion Interface Placement

Expansion headers are positioned at the board perimeter.

Interfaces:

- I²C Header
- UART3 Header
- Debug Connections

Benefits:

- Easy access
- Future module integration
- Reduced wiring complexity

---

# Routing Strategy

Routing was performed according to signal function.

---

# Power Routing

Power traces are prioritized.

Goals:

- Low voltage drop
- Low impedance
- Reliable current delivery

Methods:

- Wide traces
- Power pours
- Plane utilization

---

# Signal Routing

Signal traces were routed with emphasis on:

- Short path lengths
- Noise avoidance
- Reduced crossing

Sensitive signals include:

- BMS_ALERT
- Current Sense
- Voltage Sense
- UART Interfaces
- I²C Interfaces

---

# Analog Signal Routing

Special consideration was given to analog measurement signals.

Signals:

- FB_NODE
- CURRENT_SENSE_OUT

Objectives:

- Reduce noise
- Improve measurement accuracy
- Maintain ADC integrity

---

# Grounding Strategy

A dedicated ground plane is used.

Benefits:

- Reduced noise
- Improved return current paths
- Enhanced signal integrity

---

# Grounding Philosophy

The design separates noisy and sensitive circuitry through placement and routing practices while maintaining a unified ground reference.

Objectives:

- Minimize ground loops
- Reduce switching noise coupling
- Improve ADC measurements

---

# Power Distribution Architecture

The PCB distributes power through dedicated rails.

## SYS_VBAT

Primary battery rail.

Purpose:

- Battery distribution
- Protection stage supply

---

## V12_SYS

12V system rail.

Purpose:

- External loads
- Future peripherals

---

## V5_SYS

5V system rail.

Purpose:

- Logic support
- Expansion modules

---

## 3V3_SYS

3.3V rail.

Purpose:

- STM32
- BQ76920 interfaces
- Logic circuitry

---

# Thermal Design

Thermal management was considered throughout the layout process.

Methods:

- Copper spreading
- Power plane utilization
- Strategic component placement

---

# Thermal Considerations

Highest thermal contributors:

- Power MOSFETs
- Power conversion circuitry
- Voltage regulators

Design Objectives:

- Heat spreading
- Reduced hotspots
- Reliable operation

---

# Decoupling Strategy

Every major IC includes local decoupling capacitors.

Objectives:

- Stable operation
- Reduced transient noise
- Improved supply integrity

---

# EMI Considerations

The layout incorporates basic EMI-conscious practices.

Methods:

- Ground plane usage
- Controlled return paths
- Short critical traces
- Functional partitioning

---

# Design Rule Check (DRC)

Before manufacturing, the PCB should pass:

- Clearance checks
- Short circuit checks
- Unconnected net checks
- Silk screen checks
- Hole validation
- Polygon validation

---

# Manufacturing Readiness

The PCB design package includes:

- PCB Layout
- Schematics
- Draftsman Documentation
- Gerber Files
- NC Drill Files
- BOM

---

# Draftsman Documentation

Generated documentation includes:

## Assembly Drawing

Provides:

- Component placement
- Reference designators
- Assembly guidance

---

## Layer Documentation

Provides:

- Layer information
- Routing visibility
- PCB structure reference

---

## Manufacturing Documentation

Provides:

- Fabrication information
- Board specifications
- Production references

---

# Design Review Checklist

Before fabrication verify:

- All connectors labeled
- Polarized components verified
- BQ76920 pin mapping checked
- STM32 pin mapping checked
- Decoupling capacitors present
- DRC clean
- Silkscreen verified
- Drill files generated
- Gerbers generated
- BOM generated

---

# Known Revision-A Notes

## PV Voltage Measurement

Revision A reserves PA3 for future photovoltaic voltage measurement but does not directly acquire PV voltage.

Future revisions may add:

- External voltage divider
- Dedicated sensing interface
- Advanced MPPT functionality

---

# PCB Design Philosophy

The PCB was designed to serve as a modular development platform rather than a fixed-function charger.

The architecture emphasizes:

- Scalability
- Expandability
- Maintainability
- Embedded Development
- Power Electronics Learning
- Professional PCB Design Practices

The design supports future growth into:

- MPPT Systems
- Wireless Monitoring
- Industrial Communication
- Data Logging
- Advanced Battery Analytics

---

## Revision Information

Document Version: 1.0

Board Revision: Rev A

Project:

SolarCore-4S MPPT Power Management System

Author:

Yukesh S

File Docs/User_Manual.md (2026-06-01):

# User Manual

## SolarCore-4S MPPT Power Management System

Version: Rev A

---

## 1. Introduction

The SolarCore-4S MPPT Power Management System is an embedded energy harvesting and battery management platform designed around the STM32F103C8T6 microcontroller and BQ76920 battery monitoring IC.

The platform combines:

- Solar energy harvesting
- Future MPPT control capability
- 4S LiFePO4 battery management
- Charge and discharge protection
- Power distribution
- USB-C debugging
- OLED expansion support
- ESP32 expansion support

This document describes hardware operation, connectors, indicators, and system usage.

---

## 2. Safety Information

Before using the board:

- Verify battery polarity.
- Verify solar panel polarity.
- Never short battery terminals.
- Never exceed battery voltage limits.
- Verify all wiring before applying power.
- Use appropriate fuses where required.
- Disconnect power before modifying connections.

---

## 3. Supported Battery Configuration

| Parameter | Value |
|---|---|
| Battery Type | LiFePO4 |
| Configuration | 4S |
| Nominal Voltage | 12.8V |
| Maximum Voltage | 14.6V |
| Monitoring IC | BQ76920 |

---

## 4. System Overview

The board contains the following major subsystems:

1. STM32 Control System
2. Battery Management System
3. Charge Protection
4. Discharge Protection
5. Power Distribution
6. USB-C Programming Interface
7. User Interface Indicators
8. Expansion Interfaces

---

## 5. Power-Up Sequence

Recommended startup sequence:

1. Connect battery pack.
2. Verify battery LEDs illuminate.
3. Verify power LED operation.
4. Connect solar panel input.
5. Verify charging indication.
6. Connect external loads if required.

---

## 6. Battery Connection

### Battery Connector

Connect:

```text
B+
B1
B2
B3
B-
```

according to the battery pack cell order.

Incorrect balance wiring may trigger BMS protection or damage monitoring circuitry.

Before connection:

- Measure cell voltages.
- Verify wiring sequence.
- Verify connector orientation.

---

## 7. Solar Input Connection

Connect photovoltaic input to:

```text
PV+
PV-
```

Recommended checks:

- Verify polarity.
- Verify open-circuit voltage.
- Verify connector integrity.

Current hardware revision does not directly measure PV voltage.

Future revisions may use the reserved PV sensing input on PA3 together with an external voltage divider interface.

---

## 8. Output Connections

The board provides regulated system power rails.

### Available Rails

| Rail | Purpose |
|---|---|
| SYS_VBAT | Battery Output |
| V12_SYS | 12V Distribution |
| V5_SYS | 5V Distribution |
| 3V3_SYS | Logic Supply |
| VBOOST_OUT | Boost Converter Output |

These rails may be used to power external electronics and future expansion modules.

---

## 9. USB-C Programming Interface

The board includes a USB Type-C interface connected to a CP2102N USB-UART bridge.

Functions:

- Firmware upload
- Serial debugging
- Diagnostic logging
- Development support

### UART Mapping

| Signal | STM32 Pin |
|---|---|
| UART1_TX | PA9 |
| UART1_RX | PA10 |

---

## 10. OLED Expansion Header

An I²C expansion header is available for OLED displays and other peripherals.

### STM32 Connections

| Signal | Pin |
|---|---|
| SDA | PB6 |
| SCL | PB5 |

### Supported Future Features

- Battery voltage display
- Battery percentage
- Fault codes
- Charging status
- Output status
- System diagnostics

Recommended Display:

SSD1306 OLED

---

## 11. ESP32 Expansion Header

UART3 is reserved for wireless expansion.

### STM32 Connections

| Signal | Pin |
|---|---|
| UART3_TX | PB10 |
| UART3_RX | PB11 |

Potential applications:

- WiFi monitoring
- MQTT
- Cloud connectivity
- Mobile applications
- Remote telemetry
- Home Assistant integration

---

## 12. User Button

### STM32 Pin

```text
PA1
```

Potential firmware functions:

- Wake-up
- Menu navigation
- Status display
- Diagnostics mode
- Factory reset

Actual behavior depends on firmware implementation.

---

## 13. Battery Level LEDs

### STM32 Pins

| LED | Pin |
|---|---|
| BAT_LEVEL1 | PB0 |
| BAT_LEVEL2 | PB1 |
| BAT_LEVEL3 | PB2 |
| BAT_LEVEL4 | PB3 |
| BAT_LEVEL5 | PB4 |

Normal operation:

| Battery Level | LEDs |
|---|---|
| 0–20% | LED1 |
| 20–40% | LED1–LED2 |
| 40–60% | LED1–LED3 |
| 60–80% | LED1–LED4 |
| 80–100% | LED1–LED5 |

---

## 14. Buzzer

### STM32 Pin

```text
PB7
```

The buzzer is fully firmware-controlled.

Recommended indications:

| Event | Pattern |
|---|---|
| Startup | Single Beep |
| Charging Started | Double Beep |
| Charge Complete | Triple Beep |
| Low Battery | Periodic Beep |
| BMS Fault | Long Tone |

The buzzer frequency and patterns may be modified through firmware.

---

## 15. BMS Monitoring

The BQ76920 monitors:

- Cell Voltage
- Overvoltage
- Undervoltage
- Charge Overcurrent
- Discharge Overcurrent

### Alert Line

| Signal | STM32 Pin |
|---|---|
| BMS_ALERT | PA0 |

The MCU uses this signal to detect protection events.

---

## 16. Future Expansion Features

Reserved MCU resources enable future capabilities:

- CAN Communication
- RS485
- Temperature Monitoring
- Fan Control
- Data Logging
- Smart Load Control
- Wireless Connectivity
- Advanced MPPT Algorithms

---

## 17. Known Revision-A Limitation

### PV Voltage Measurement

Revision A does not directly acquire photovoltaic panel voltage.

Reserved resource:

| STM32 Pin |
|----------|
| PA3 |

Future revisions may use:

- External resistor divider
- Dedicated sensing connector
- True MPPT voltage tracking

This limitation does not affect battery management operation.

---

## 18. Troubleshooting

| Symptom | Possible Cause |
|---|---|
| No LEDs | No battery connection |
| BMS Fault LED Active | Battery protection event |
| No Charging | Solar input unavailable |
| No UART Communication | USB driver issue |
| Battery Not Detected | Wiring issue |
| Continuous Buzzer | Fault condition |

Refer to:

```text
Fault_Analysis_Guide.md
```

for detailed diagnostics.

---

## 19. Related Documentation

- STM32_Pin_Assignment.md
- LED_and_Buzzer_Behavior.md
- Fault_Analysis_Guide.md
- Hardware_Features.md
- Firmware_Feature_Specification.md
- Future_Expansion_Guide.md

---

## Revision Information

Document Version: 1.0

Board Revision: Rev A

Project:

SolarCore-4S MPPT Power Management System

Author:

Yukesh S

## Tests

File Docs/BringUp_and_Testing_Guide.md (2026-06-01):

# Bring-Up and Testing Guide

## Overview

This document defines the recommended validation procedure for the first assembled SolarCore-4S MPPT Power Management System PCB.

The objective is to verify hardware functionality safely while minimizing the risk of component damage during initial power-up.

---

## Required Equipment

### Essential

* Digital Multimeter
* Adjustable Bench Power Supply
* ST-Link Programmer
* USB Type-C Cable

### Recommended

* Oscilloscope
* Electronic Load
* Logic Analyzer
* Thermal Camera

---

## Stage 1 – Visual Inspection

Verify:

* Component placement
* Component orientation
* Solder joints
* Connector orientation
* Missing components
* Solder bridges

### Pass Criteria

* No visible assembly defects
* No damaged components
* No solder bridges

---

## Stage 2 – Continuity Testing

Check for shorts between:

* B+ and B-
* PV+ and PV-
* V12_SYS and GND
* V5_SYS and GND
* 3V3_SYS and GND

### Pass Criteria

* No short circuits detected

---

## Stage 3 – Power Rail Verification

Apply power using a current-limited bench supply.

### Verify Rails

| Rail | Expected Value |
| --- | --- |
| V12_SYS | ~12V |
| V5_SYS  | ~5V |
| 3V3_SYS | ~3.3V |

### Pass Criteria

* All rails present
* No excessive current draw
* No overheating

---

## Stage 4 – STM32 Bring-Up

Verify:

* ST-Link connection
* MCU detection
* Firmware programming
* Stable operation

### Pins

| Signal | STM32 Pin |
| --- | --- |
| SWDIO  | PA13 |
| SWCLK  | PA14 |

### Pass Criteria

* STM32 detected successfully
* Firmware upload successful

---

## Stage 5 – USB-C Debug Interface

Verify:

* CP2102N detection
* UART communication
* Serial terminal operation

### Pins

| Signal | STM32 Pin |
| --- | --- |
| UART1_TX | PA9 |
| UART1_RX | PA10 |

### Pass Criteria

* Reliable serial communication

---

## Stage 6 – User Interface Verification

### LEDs

Verify operation of:

* BAT_LEVEL1
* BAT_LEVEL2
* BAT_LEVEL3
* BAT_LEVEL4
* BAT_LEVEL5

### Buzzer

Verify:

* Startup indication
* Test tone generation

### Pass Criteria

* All indicators functional

---

## Stage 7 – BQ76920 Verification

Verify:

* Device power
* Communication
* ALERT functionality

### Signal

| Signal | STM32 Pin |
| --- | --- |
| BMS_ALERT | PA0 |

### Pass Criteria

* BQ76920 responds correctly
* ALERT line functional

---

## Stage 8 – Analog Measurement Verification

### Voltage Measurement

Verify:

| Signal  | STM32 Pin |
| --- | --- |
| FB_NODE | PA4 |

Compare ADC readings against a multimeter.

### Current Measurement

Verify:

| Signal | STM32 Pin |
| --- | --- |
| CURRENT_SENSE_OUT | PA5 |

Compare ADC readings against measured current.

### Pass Criteria

* Measurements within expected tolerance

---

## Stage 9 – Expansion Interface Verification

### I²C Header

| Signal | STM32 Pin |
| --- | --- |
| SDA | PB6 |
| SCL | PB5 |

### UART3 Header

| Signal | STM32 Pin |
| --- | --- |
| UART3_TX | PB10 |
| UART3_RX | PB11 |

### Pass Criteria

* Communication interfaces functional

---

## Stage 10 – Protection Verification

Verify:

* Battery disconnect detection
* Undervoltage response
* Overvoltage response
* Overcurrent response

### Pass Criteria

* Protection mechanisms operate correctly

---

## Future Validation

### MPPT System

Reserved Resource:

| Signal | STM32 Pin |
| --- | --- |
| PV Voltage Sense | PA3 |

Future testing will include:

* PV voltage acquisition
* MPPT control validation
* Power tracking verification

---

## Final Acceptance Checklist

### Hardware

* [ ] Visual inspection passed
* [ ] No shorts detected
* [ ] Power rails verified
* [ ] STM32 operational
* [ ] BQ76920 operational

### Interfaces

* [ ] USB-C verified
* [ ] UART1 verified
* [ ] UART3 verified
* [ ] I²C verified

### User Interface

* [ ] LEDs verified
* [ ] Buzzer verified

### Measurements

* [ ] Voltage sensing verified
* [ ] Current sensing verified

### Protection

* [ ] Undervoltage protection verified
* [ ] Overvoltage protection verified
* [ ] Overcurrent protection verified

---

## Revision Information

Document Version: 1.0

Board Revision: Rev A

Project: SolarCore-4S MPPT Power Management System

Author: Yukesh S

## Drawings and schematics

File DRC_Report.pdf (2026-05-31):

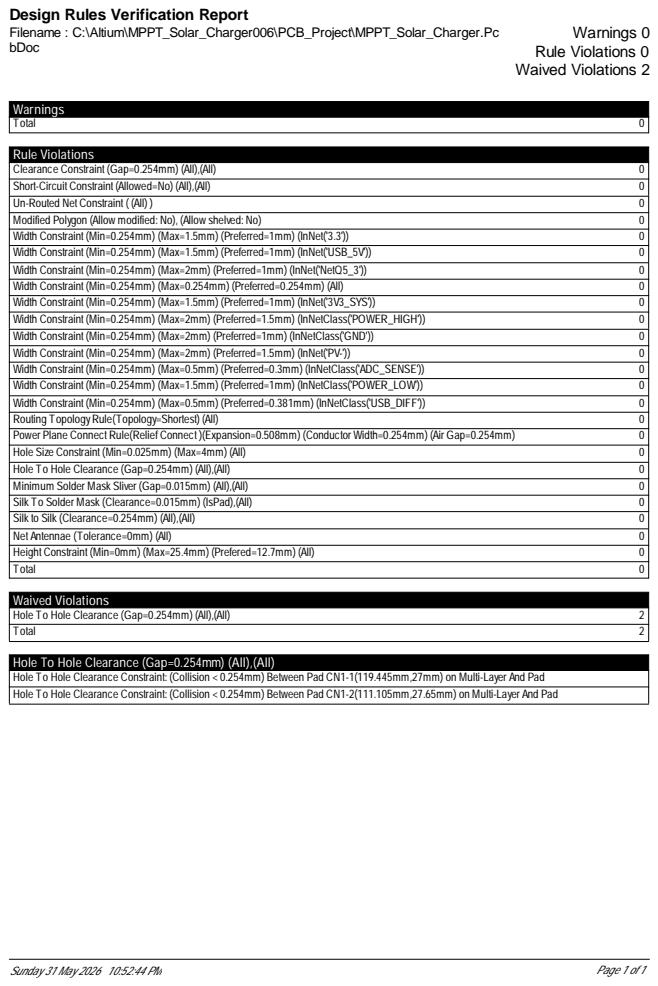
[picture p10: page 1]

Design Rules Verification Report
Filename : C:\Altium\MPPT_Solar_Charger006\PCB_Project\MPPT_Solar_Charger.Pc
bDoc

Hole To Hole Clearance (Gap=0.254mm) (All),(All)
Hole To Hole Clearance Constraint: (Collision < 0.254mm) Between Pad CN1-1(119.445mm,27mm) on Multi-Layer And Pad
Hole To Hole Clearance Constraint: (Collision < 0.254mm) Between Pad CN1-2(111.105mm,27.65mm) on Multi-Layer And Pad

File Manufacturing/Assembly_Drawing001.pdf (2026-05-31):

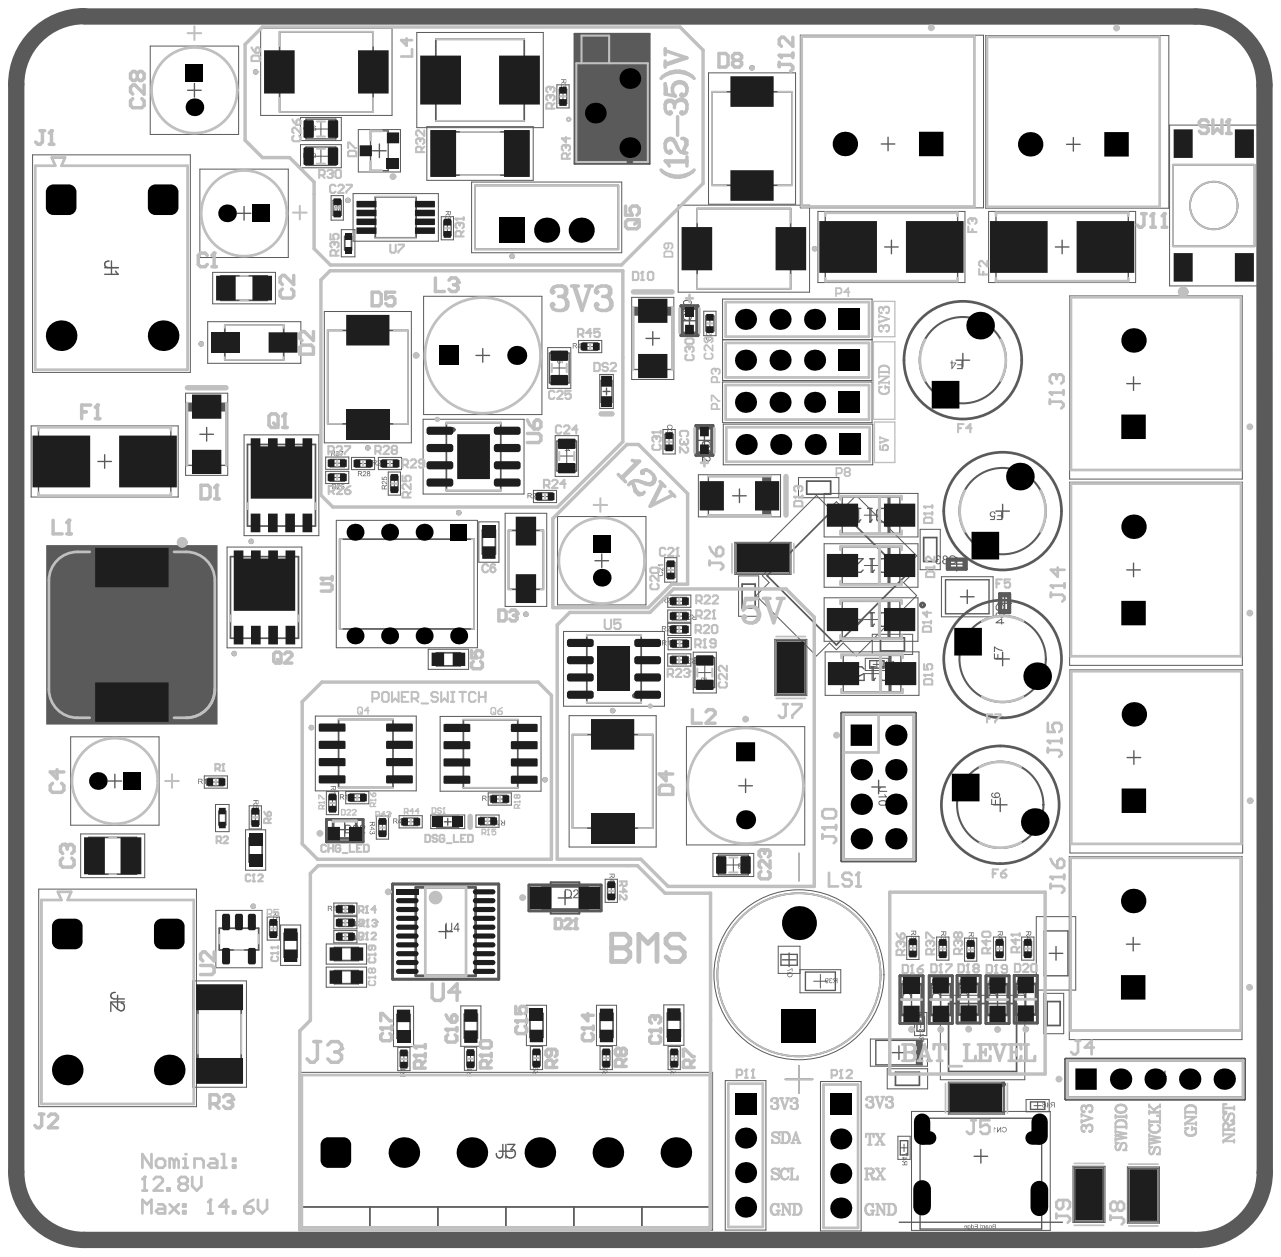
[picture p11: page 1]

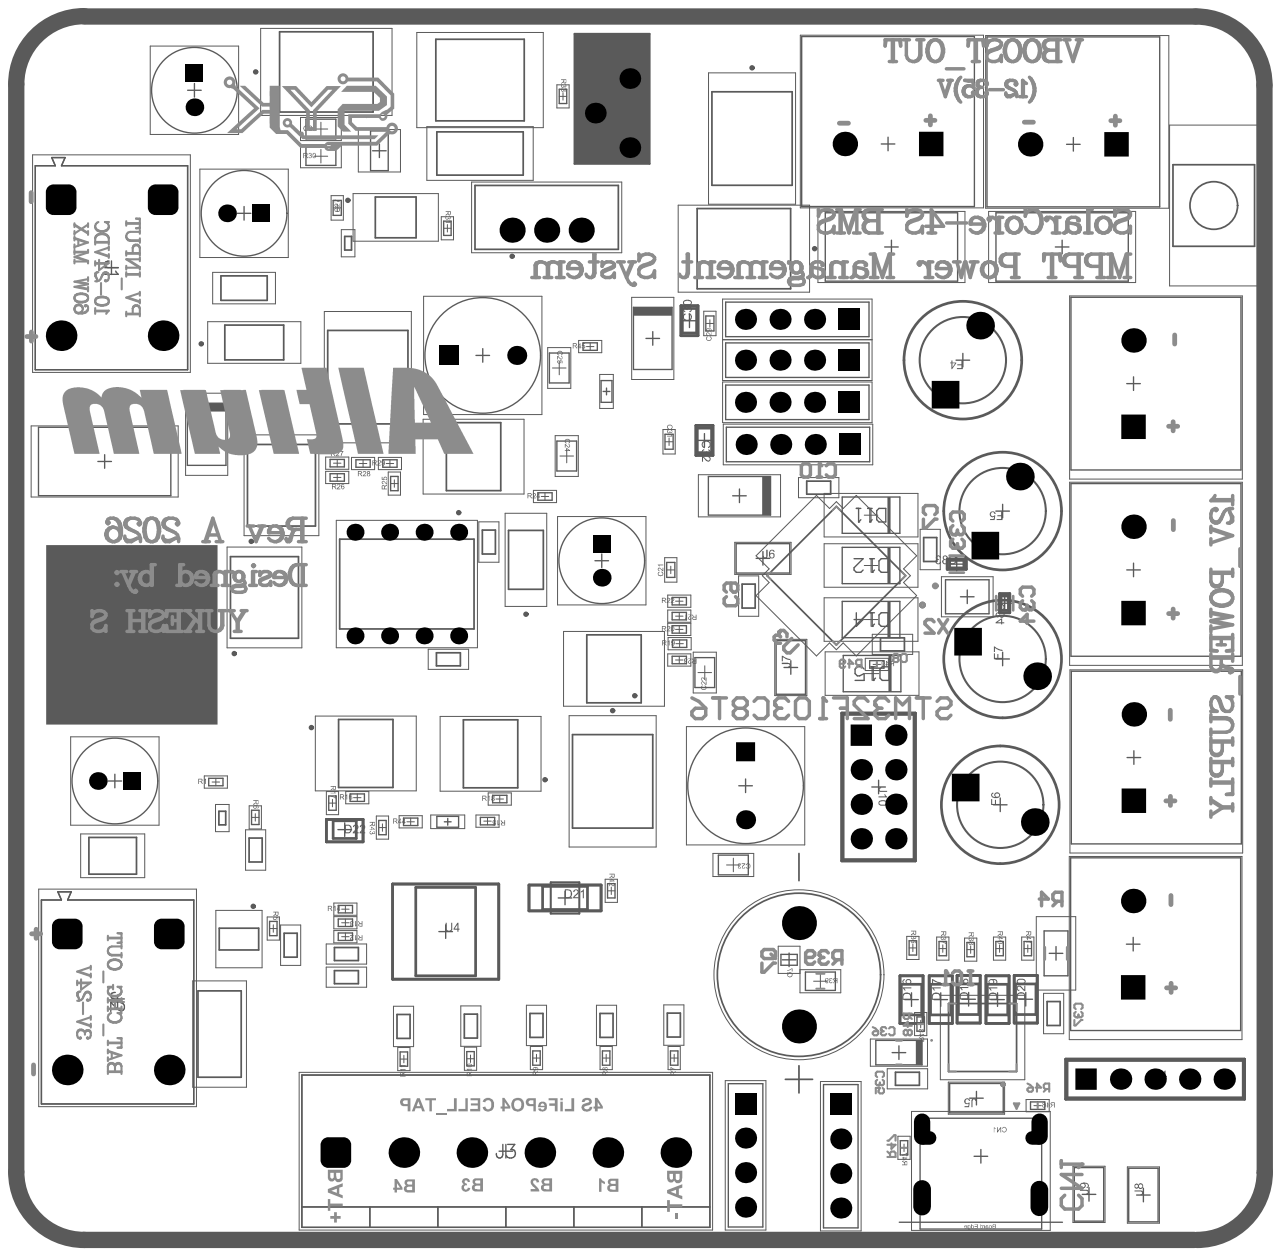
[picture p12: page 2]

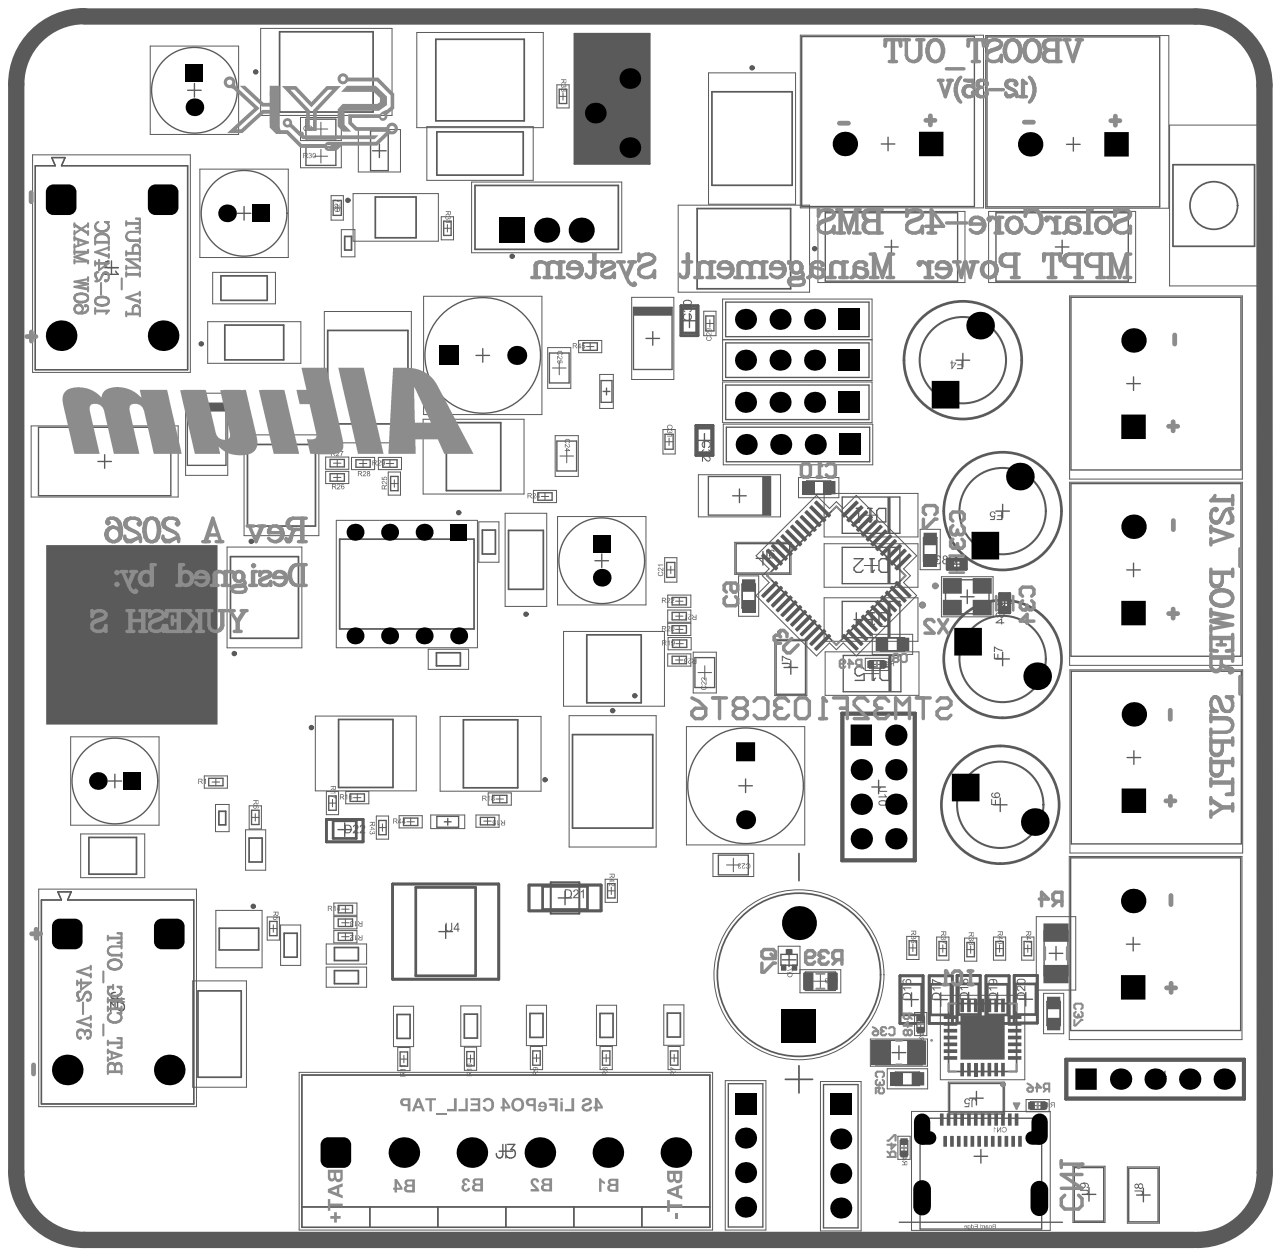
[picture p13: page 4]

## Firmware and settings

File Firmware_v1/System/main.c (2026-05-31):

/*
Project     : MPPT Solar Power Supply
File        : main.c

Description :
Main firmware entry point.

Developer Notes :

* Initializes the firmware.
* Executes scheduler tasks.
* Executes state machine.
* Avoid placing application logic directly here.
* Keep main loop clean.
  */

#include "system/system.h"

#include "application/scheduler.h"
#include "application/state_machine.h"

int main(void)
{
scheduler_flags_t *pScheduler;

```
// Initialize complete firmware
System_Init();

// Get scheduler flags structure
pScheduler = Scheduler_GetFlags();

while(1)
{
    // Execute state machine every loop
    StateMachine_Run();

    // 1ms Tasks
    if(pScheduler->Task_1ms)
    {
        pScheduler->Task_1ms = 0;

        // Future 1ms tasks
    }

    // 10ms Tasks
    if(pScheduler->Task_10ms)
    {
        pScheduler->Task_10ms = 0;

        // Button handling
        // Buzzer handling
    }

    // 100ms Tasks
    if(pScheduler->Task_100ms)
    {
        pScheduler->Task_100ms = 0;

        // Battery monitoring
        // Sensor updates
    }

    // 500ms Tasks
    if(pScheduler->Task_500ms)
    {
        pScheduler->Task_500ms = 0;

        // OLED update
    }

    // 1000ms Tasks
    if(pScheduler->Task_1000ms)
    {
        pScheduler->Task_1000ms = 0;

        // Debug messages
    }
}
```

}

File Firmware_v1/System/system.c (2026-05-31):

/*
Project     : MPPT Solar Power Supply
File        : system.c

Description :
System initialization implementation.

Developer Notes :

* Initializes all firmware modules.
* Called once during startup.
* Keep startup sequence centralized.
  */

#include "system.h"

// Drivers

#include "../drivers/gpio.h"
#include "../drivers/uart.h"
#include "../drivers/adc.h"
#include "../drivers/ina180.h"
#include "../drivers/pwm.h"

// Application

#include "../application/scheduler.h"
#include "../application/state_machine.h"
#include "../application/fault.h"
#include "../application/battery.h"
#include "../application/buzzer.h"
#include "../application/mppt.h"
#include "../application/display.h"

// Initialize complete firmware system
void System_Init(void)
{
// Drivers

    GPIO_Init();
    UART_Init();
    ADC_Driver_Init();
    INA180_Init();
    PWM_Init();

    // Application Modules

    Scheduler_Init();

    Fault_Init();

    Battery_Init();

    Buzzer_Init();

    MPPT_Init();

    Display_Init();

    StateMachine_Init();

}
